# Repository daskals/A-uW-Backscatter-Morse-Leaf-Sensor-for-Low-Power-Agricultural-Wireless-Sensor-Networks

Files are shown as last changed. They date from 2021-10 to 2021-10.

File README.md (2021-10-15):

# A uW Backscatter-Morse-Leaf Sensor for Low-Power Agricultural Wireless Sensor Networks
Design files of IEEE publication: A uW Backscatter-Morse-Leaf Sensor for Low-Power Agricultural Wireless Sensor Networks

Nowadays, the monitoring of plant water stress
is of high importance in smart agriculture. Instead of the
traditional ground soil-moisture measurement, leaf sensing is a
new technology, which is used for the detection of plants needing
water. In this work, a novel, low-cost and low-power system for
leaf sensing using a new plant backscatter sensor node/tag is
presented. The latter, can result in the prevention of water waste
(water-use efficiency), when is connected to an irrigation system.
Specifically, the sensor measures the temperature differential
between the leaf and the air, which is directly related to the plant
water stress. Next, the tag collects the information from the leaf
sensor through an analog-to-digital converter (ADC), and then,
communicates remotely with a low-cost software-defined radio
(SDR) reader using monostatic backscatter architecture. The tag
consists of the sensor board, a microcontroller, an external timer
and an RF front-end for communication. The timer produces a
subcarrier frequency for simultaneous access of multiple tags.
The proposed work could be scaled and be a part of a large
backscatter wireless sensor network (WSN). The communication
protocol exploits the low-complexity Morse code modulation on
a 868 MHz carrier signal. The presented novel proof-of-consent
prototype is batteryless and was powered by a flexible solar panel
consuming power around 20 µW. The performance was validated
in an indoors environment where wireless communication was
successfully achieved up to 2 m distance.

**Authors:**

Spyridon Nektarios Daskalakis\
Stylianos D. Assimonis\
George Goussetis\
Manos M. Tentzeris\
Apostolos Georgiadis

---
IEEE Xplore: https://ieeexplore.ieee.org/document/8423620 \
Local: http://daskalakispiros.com/files/daskalalakis_sensors_2018.pdf

---

---
**Questions/issues**
Inquiries regarding the scripts provided are cordially welcome.

---
**Citing**

If you use our design, please cite [[1]](https://ieeexplore.ieee.org/document/8423620).

```bibtex
@article{daskalakis2018uw,
  title={A uW backscatter-morse-leaf sensor for low-power agricultural wireless sensor networks},
  author={Daskalakis, Spyridon Nektarios and Goussetis, George and Assimonis, Stylianos D and Tentzeris, Manos M and Georgiadis, Apostolos},
  journal={IEEE Sensors Journal},
  volume={18},
  number={19},
  pages={7889--7898},
  year={2018},
  publisher={IEEE}
}
 
```

[[1]](https://ieeexplore.ieee.org/document/8423620) S. N. Daskalakis, G. Goussetis, S. D. Assimonis, M. M. Tentzeris and A. Georgiadis, A uW Backscatter-Morse-Leaf Sensor for Low Power Agricultural Wireless Sensor Networks, IEEE Sensors Journal, Vol. 18, No. 19, pp. 7889–7898, Oct. 2018.

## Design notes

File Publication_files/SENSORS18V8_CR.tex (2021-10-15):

\documentclass[journal]{IEEEtran}

\usepackage{mathtools}
\usepackage{amsmath}
\usepackage{amssymb}
\usepackage{graphicx}
\usepackage{epstopdf}
\usepackage{cite}
\usepackage{array}
\usepackage{eurosym}
\usepackage{balance}
\usepackage{url}

\usepackage{color}

\newcommand{\hilight}[1]{\colorbox{yellow}{#1}}

\newcommand{\highlight}[1]{%
  \colorbox{yellow}{$\displaystyle#1$}}

\hyphenation{op-tical net-works semi-conduc-tor mo-nitoring}
\newcommand\blfootnote[1]{%
  \begingroup
  \renewcommand\thefootnote{}\footnote{#1}%
  \addtocounter{footnote}{-1}%
  \endgroup
}

\begin{document}
\title{A uW Backscatter-Morse-Leaf Sensor for Low-Power Agricultural Wireless Sensor Networks}

\author{

\IEEEauthorblockN{Spyridon N. Daskalakis,~\IEEEmembership{Student Member,~IEEE}, 
George Goussetis,~\IEEEmembership{Senior Member,~IEEE},
Stylianos D. Assimonis,
Manos M. Tentzeris,~\IEEEmembership{Fellow,~IEEE} and 
Apostolos Georgiadis,~\IEEEmembership{Senior Member,~IEEE}
}
                             
%\vspace{-1cm}
\thanks{
This work was supported by Lloyd's Register Foundation (LRF) and the International Consortium in Nanotechnology (ICON). The work of M. M. Tentzeris was supported by the National Science Foundation (NSF) and the Defense Threat Reduction Agency (DTRA).

An earlier version of this paper was presented at the  IEEE Sensors Conference, Glasgow, United Kingdom, 29 Oct - 01 Nov 2017  and was published in its Proceedings. Conference version of  this paper is available online at http://ieeexplore.ieee.org/document/8233888/.

S. N. Daskalakis, G. Goussetis and A. Georgiadis  are with School of Engineering \& Physical Sciences;  Institute of Sensors, Signals and Systems, Heriot-Watt University, Edinburgh, EH14 4AS, Scotland,
UK (e-mail: sd70@hw.ac.uk, g.goussetis@hw.ac.uk, apostolos.georgiadis@ieee.org).

S. D. Assimonis is with School of Electronics, Electrical Engineering \& Computer Science, Queen's University Belfast, Belfast, BT3  9DT, UK (e-mail: s.assimonis@qub.ac.uk).

M. M. Tentzeris is with School of Electrical and Computer Engineering, Georgia Institute of Technology, Atlanta, GA, 30332-250, USA (e-mail: etentze@ece.gatech.edu).

}}

\maketitle

\begin{abstract}
Nowadays, the monitoring of  plant water stress is of high importance in smart agriculture.
%
Instead of the traditional ground soil-moisture measurement, leaf sensing is a new technology, which is used for the detection of plants needing water.
%
In this work, a novel, low-cost and low-power system for leaf sensing using a new plant backscatter sensor node/tag is presented.
%
The latter, can result in the prevention of water waste (water-use efficiency), when is connected to an irrigation system.
%
Specifically, the sensor  measures the temperature differential between the leaf and the air, which is directly  related to the plant water stress.
%
Next, the tag collects the information from the leaf sensor through an analog-to-digital converter (ADC), and then, communicates remotely with 
a low-cost software-defined radio (SDR) reader  using monostatic backscatter architecture.
%
The tag  consists of  the sensor board, a microcontroller, an external timer  and an RF front-end for communication.
%
The timer produces a subcarrier frequency  
for simultaneous access of multiple tags.
%
The proposed work could be scaled and be a part of a large 
backscatter wireless sensor network (WSN). 
%
The communication protocol exploits 
the low-complexity  Morse code modulation
on a $868$~MHz carrier signal.
%
The presented novel  proof-of-consent prototype is batteryless and was powered by a flexible solar panel consuming power around $20~\mu$W.  
%
The performance was validated in an indoors environment where wireless communication was successfully achieved up to $2$~m distance.
%
\end{abstract}

\begin{IEEEkeywords}
Backscatter sensor networks, environmental monitoring, Internet-of-Things (IoT), leaf sensor, Morse code, precision agriculture, radio frequency identification (RFID) sensors, software-defined radio (SDR). 
\end{IEEEkeywords}

\IEEEpeerreviewmaketitle

\section{Introduction}
\label{sec:intro}
Precision agriculture allows farmers to maximize yields using minimal resources such as water, fertilizer, pesticides and seeds. 
%
By deploying sensors and monitoring fields, farmers can manage their crops at micro scale  \cite{ivanov2015precision}.
% 
This is also useful in order to predict diseases, conserve the resources and reduce the impacts of the environment. 
%
%Smart agriculture has roots going back to the 1980s when Global Positioning System (GPS) capability became accessible for civilian use. 
%
%Once farmers were able to accurately map their crop fields, they could monitor and apply fertilizer and weed treatments only to areas that required it. 
%
During the 1990s, early precision agriculture users adopted crop yield monitoring to generate fertilizer and pH correction recommendations. 
%
As more variables could be measured by sensors and were introduced into a crop model, more accurate recommendations could be made.
%
The combination of the aforementioned systems with wireless sensor networks (WSNs) allows multiple unassisted embedded devices (sensor nodes) to transmit  wirelessly data to central base stations \cite{ruiz2009review, yu2009zigbee}.
%
The base stations are able to store the data into cloud databases
for worldwide processing and visualization  \cite{fahmi2017prototype}. 
% 
Data (e.g., temperature, humidity, pressure) are collected from different on-board physical sensors: dielectric soil moisture sensors, for instance,  are widespread  for moisture measurements, since they can estimate the moisture levels through the dielectric constant of the soil, which changes as the soil moisture is changing.

%
Leaf sensing is an another way to measure the water status of a plant. 
%
When compared to soil moisture sensors, they can provide more accurate data since the measurements are directly taken on the plant and not through the soil or the atmosphere (air), which surround the latter \cite{palazzari2017leaf}. 
%
Commercial   leaf sensors  are involve   phytometric devices  that measure  the water deficit stress (WDS) by monitoring the moisture level in plant leaves. 
%
In recent work \cite{seelig2012irrigation}, a leaf sensor is used to measure the plant's leaf thickness in order to determine the WDS.
%
The  sensor is provided by  AgriHouse Inc.  and it is suitable for  real-time monitoring in  aeroponics, hydroponics and drip irrigation systems \cite{SG-1000}.
%
In an extreme WDS scenario, the leaf thickness decreased dramatically (by as much as $45$\%) within a short period of time ($2$~hours). 
%
On other occasions, the leaf thickness was kept fairly constant for several days, but decreased substantially when WDS became too severe for the plant \cite{seelig2012irrigation}.
%
Despite such favourable features, this class of sensors can only be used  in controlled environments (i.e., greenhouses) in  combination with other type of  sensors.
%
This is because a direct relationship seems to exist between leaf thickness and the relative humidity of the ambient air, temperature, soil temperature and soil salinity\cite{seelig2012irrigation}.  
%

A different type of leaf sensor for WDS monitoring,  is described in \cite{palazzari2017leaf} and is using two  temperature sensors.
%
The monitoring is based on  the temperature difference between the leaf and the air ($T_\text{leaf}- T_\text{air}$). 
% 
This difference is strictly related to the plant water stress and can be used as decision parameter in a  local irrigation system \cite{abraham2000irrigation}.
%
The first sensor measures the canopy temperature on  the leaf ($T_\text{leaf}$)  and the second the atmospheric temperature ($T_\text{air}$).
%
The use of canopy temperature as an indicator of crop water stress has been the subject of much research over the past $30$ years \cite{patel2001canopy}.
%
Canopy temperature and water stress are related: 
when the soil moisture is reduced,   stomatal closure occurs on the leaves resulting to reduced   transpirational cooling. 
%
The canopy temperature is then increased above that of the air
\cite{pearcy1971photosynthetic}.
%
In a plant with adequate water supply, the term  $T_\text{leaf}- T_\text{air}$ will be zero or negative, but
when the available water is limited, the difference will be
positive.

\begin{figure}[t]
\centering

\caption{Monostatic backscatter communication setup. Plant sensing is achieved by the tags and the information is sent back to a low-cost reader. Information is modulated using Morse coding on a $868$~MHz radiated carrier.}
\label{fig:backscatterlogic}
\end{figure}
The leaf sensors that were described above   are different from the well known leaf wetness  sensors (LWS).
%
The LWS can  detect the leaf wetness which is a meteorological parameter that describes the amount of dew and precipitation left on leaf surfaces. 
%
Leaf wetness can result from dew, fog, rain, and overhead irrigation.
%
Today, the LWS   are used most for  disease-warning systems 
\cite{hornero2017novel} and provided by companies like Davis Instruments Inc. and Meter Environment  Inc. \cite{PHYTOS-31}. 

The agricultural applications frequently involve large, expansive areas where wire connection for communication and power is undesirable or impracticable \cite{ruiz2009review}. 
%
The high-cost and the high-power requirements of the today WSN hardware prevent its usage in agriculture.
%
The deployment of these systems therefore relies  on reducing the cost to an affordable amount. 
%
Capital expenditure relates to the cost of the hardware, which should therefore be maintained minimum.
%
Energy autonomy for the sensor achieved by a combination of minimizing power consumption and harvesting ambient energy is likewise critical in order to reduce operational costs. 
%
Above factors drive the demand for low-cost, low-power WSN systems.

Backscatter radio communication (i.e., reflection and modulation of an incident radio frequency carrier) 
in combination with the use of energy assisted (or not) sensor tags is a method  that addresses aforementioned constraints.
%
It is used in radio frequency identification (RFID)
applications and offers ultra-low-power and low-cost aspects \cite{sample2008design}.  
%
The  wireless communication part of each tag can be 
simplified into a single radio frequency  (RF) transistor and an antenna, 
which can be used for each sensor tag to send information to a base station (reader).
%
It is a very energy-efficient communication technique
thus the RF signal is used not only for the communication, but also, for the power of the tag \cite{assimonis2015sensitive}.
%
In the recent literature,  backscatter WSNs  for smart agriculture purposes  \cite{daskalakis2016soil, kampianakis2014wireless, konstantopoulosconverting, pichorim2018two} were proposed. 
%
In \cite{daskalakis2016soil, kampianakis2014wireless},
soil moisture  and humidity  sensors were proposed.
%
A proof of concept demonstration was presented where the tags send measurements to a software-defined radio (SDR)
reader. 
%
The WSNs  employ semi-passive tags in bistatic topology and
each backscatter sensor tag has power consumption of the order of $1$~mW.
%
The achieved communication range  (tag-reader distance) is of the order of $100$~m; this is achieved by supplying the tags with small batteries thereby enabling increased communication range.
%
In \cite{konstantopoulosconverting},  electric potential (EP) signals of plants can be measured by the tag in order to estimate when the plant needs water; in this work, the tags are batteryless and they harvest energy from the plant itself.
%
In \cite{pichorim2018two}  two UHF RFID sensor nodes  for soil moisture sensing were designed based on conventional RFID chips.

This work discusses the implementation of a low-cost and low-power wireless sensor system for agricultural applications, which uses a novel plant, backscatter sensor node/tag.
%
Preliminary results on this sensor node were proposed in \cite{daskalakis2017backscatter}.
%
The tag is connected with a temperature leaf sensor board  for WDS measurements and reflects RF signals from a carrier emitter.
%
It is noted that the proposed system can be a part of a backscatter WSN, transmitting   data to a reader as shown in Fig.~\ref{fig:backscatterlogic}.
%
Specifically the tag architecture  consists of a microcontroller (MCU) and an external timer for the modulation.
%
There is also a sensor board for the   measurements and
an FR front-end for the backscatter communication.
%
The tag reads the information from the sensors and generates pulses that control an RF switch. 
%

The low complexity Morse code technique was selected for the backscatter modulation and it is the first time that  Morse code is used in a backscatter WSN system. 
%
Morse code uses On-Off-Keying (OOK) modulation  which means that a  frequency  signal exists in only two states either ``On" or  ``Off".
%
Morse code and OOK contribute to architectural and power consumption efficiencies for the tag.
%
A low-cost   SDR is used as  reader and collects the signals for further processing. 
%
The $868$~MHz in the European RFID band was selected as carrier emitter frequency.

The structure of the this paper  is as follows: Section~\ref{sec:Backscatter_morse} provides the basic principles of backscatter  communication and the Morse encoding.
%
In  Section~\ref{sec:tag} the design  and the implementation of the tag is described. 
%
Section~\ref{sec:receiver} discusses the hardware and software part of the low-cost
receiver. 
%
Section~\ref{sec:exp} presents the  proof-of-concept experimental setup and a communication indoor demo.
%
In Section~\ref{sec:comparison}, the benefits of our proposed low-power WSN and future work are discussed.
%
Finally, section~\ref{sec:conclusion} includes concluding remarks.

\section{Backscatter and Morse Encoding}
\label{sec:Backscatter_morse}

\begin{figure}[t]
\centering

\caption{Left: In Backscatter principle when a $F_c$ carrier  exists 
and the RF switch frequency is $F_\text{tag}$, two subcarriers appear with frequencies $F\text{c} \pm F_\text{tag}$.
Right: Morse code symbols.}
\label{fig:morse}
\end{figure}

A typical  backscatter communication system requires three devices: a tag, an emitter and a reader. 
%
Traditional batteryless RFID systems utilize monostatic architectures, where the reader and the emitter are  in the same box.
%
In this work this architecture is employed; the emitter transmits a continuous wave (CW) signal at frequency $F_\text{c}$ = $868$~MHz.
%
The tag receives  and scatters a fraction of it back to the reader as shown in Fig.~\ref{fig:backscatterlogic}.
%
The backscatter binary communication can be implemented on the tag using an RF switch, an antenna and a control unit.
%
The switch  alternates the load of the antenna between two values ($Z_{1/2}$) and offers two reflection coefficients, ($\Gamma_{1/2}$), according to
%	
\begin{align}
\Gamma_\text{1/2}=\frac{Z_\text{1/2}-Z^{*}_\text{a}}{Z_\text{1/2}+Z_\text{a}},
\label{eq:gamma}
\end{align}
%
with  $Z_\text{a}$,  the antenna impedance  equal with $50$~Ohm. 
%
When the CW  with frequency $F_\text{c}$ arrives on the antenna
and the  RF switch frequency is $F_\text{tag}$, frequency modulation occurs and two subcarriers appear in the spectrum with frequencies $F_{\text{sub1/2}} = F_{\text{c}} \pm F_{\text{tag}}$.
%
The reflected signal (subcarriers) and the carrier  are depicted in Fig.~\ref{fig:morse} (left). 
%
The subcarriers are  next modulated  using the Morse code scheme as it is described below.

Morse code is a method of transmitting text information as a series of On-Off tones, named after the inventor of the telegraph Samuel F. B. Morse  in the 1830s \cite{fahie1884history}.
%
It is referred as the earliest type of binary digital communications
since the code is made solely from ones and zeros (``On" and ``Off"). 
%
%In modern times Morse code is still used widely in amateur radio communications, as Morse  coded signals can get a message through noise, whereas a voice signal often cannot.
%
Each letter of the alphabet is translated to combinations of dots  ``."  and dashes  ``-" that are sent over telegraph wires or by radio waves from one place to another.
%
For example, the  letter ``A" is translated to the sequence ``.-" with elements one dot and one dash symbol.
%
Lets assume that  the duration of a dot ($T_\text{dot}$) is one unit, then  the duration a dash is three units ($3T_\text{dot}$). 
%
Dot and dash symbols are followed by a short silence, equal to one unit (Fig.~\ref{fig:morse}, right). 
%
The space between the elements of one letter/character is one unit, between characters is three units and between words, seven units.

\begin{figure}[t]
\centering

\caption{Printed circuit boards of the tag and the solar cell.
The  watchdog timer (top) and the timer  module (bottom)  are connected with the main processor unit in the middle.}
\label{fig:PCBs}
\end{figure}
The Morse code is the only digital modulation  designed to be easily read without a computer.
%
Today it is usually used by radio amateurs and it is the  fist time that is used in backscatter communication.
%
The OOK modulation is  used to transmit Morse code signals  over  a  fixed radio frequency.
%
The OOK  is a simplest form of amplitude-shift keying (ASK) modulation that can represent digital data using  a presence (``On") or an absence (``Off") of a carrier signal.
%
With  OOK modulation and thus Morse code,  the complexity of the receiver and the tag is drastically simplified compared to a frequency modulation (FM) scheme thus there is no need for a different frequency for each symbol \cite{proakis2008digital}.
%
Also, Morse code was designed so that the most frequently used letters have the shortest codes. In general, code length increases as frequency decreases. 

In this work the ``."  (dot of Morse code) is implemented as a  signal with a specific duration $T_\text{dot}$ and frequency $F_\text{tag}$.
%
As it is expected the ``-"  (dash in Morse code) is then implemented using a signal of the same frequency with duration equal to three times that of the dot signal.
%
The $T_\text{dot}$ is defined by the MCU and the  $F_\text{tag}$ is defined by the external timer of the tag.
%
The dot and dash frequency signals are shown in Fig.~\ref{fig:morse} (left). 
%
The speed of Morse code is stated in words per minute (WPM) and 
according to the standards, the word PARIS is used to determine it. 
%
The word is translated to exactly $50$ units and  one dot duration is defined by the formula:
$T_\text{dot} = 1200 / \text{WPM}$ with $T_\text{dot}$ in ms. 

\section{Tag Implementation}
\label{sec:tag}

\subsection{Main Unit}
\label{subsec:mainunit}

\begin{figure}[t]
\centering

\caption{The schematic of the tag's main unit. The main part, is a low-power MCU that controls the sensors, the timer and the RF front-end.}
\label{fig:main_unit}
\end{figure}

The proof-of-concept tag consists of five different parts  implemented in  different printed circuit boards (PCBs) for simplifying debugging. 
%
These parts are the MCU unit, the timer part, the watchdog timer part, the sensor board, and finally the RF front-end. 
%
The MCU unit (Fig.~\ref{fig:PCBs}, middle) is the main part of the system and it is responsible for the data sensor acquisition, the implementation of the Morse code symbols and the control of the other parts. 
%
The schematic of the main system is depicted in Fig.~\ref{fig:main_unit}.
%
The ultra-low-power $8$-bit PIC16LF1459  from Microchip with current consumption  of only $25~\mu$A/MHz at $1.8$~V \cite{PIC16LF1459} was selected for the MCU.
%
The MCU collects data from the sensor board using the embedded analog-to-digital converter (ADC) with $10$-bit resolution.
%
It contains also a digital-to-analog converter (DAC) with $5$-bit resolution.     
%
The internal $31$~kHz low-power  oscillator was utilized as clock source in order to reduce the  power consumption of the tag.
The  MCU is responsible to supply  all the other parts with  voltage when  it is necessary.
%
The main part is connected with a $\mu$W timer for the subcarrier signal ($F_\text{tag}$) production 
and an external watchdog timer to wake up the MCU from the ``sleep" operation mode. 
%
In sleep mode the MCU  current consumption was only $0.6~\mu$A at  $1.8$~V.
%

\subsection{Timers}
\label{subsec:Timers}

\begin{figure}[t]
\centering

\caption{Timer and  RF front-end schematic of the tag. The timer produces  square wave pulses with $50\%$ duty circle and supplies the RF front-end through a modulation switch (ADG902). The ADG902 switch is controlled by the MCU.}
\label{fig:timer}
\end{figure}

The timer module (Fig.~\ref{fig:PCBs}, bottom) consists of a very low-power timer (TS3002), a voltage reference and a switch.
%
It is responsible for producing the subcarrier frequency of the tag  $F_\text{tag}$ and modulating this subcarrier through the  switch. 
%
The low-power,  single-pole single-throw   (SPST) switch ADG902  was used in this case and  one of the MCU input/output (I/O) pins was programmed to provide the necessary  Morse code  pulses  for the control.
%
The implemented circuit is depicted in Fig.~\ref{fig:timer}.
%
The TS3002 is a  CMOS oscillator provided by Silicon Labs Inc., fully 
specified to operate at around $1$~V  and to consume current lower than  $5~\mu$A  with an output frequency range from $5.2$~kHz to $290$~kHz  \cite{TS3002}.
%
The timer  was supplied by  a voltage reference integrated circuit (IC) XC6504 at $1.2$~V   \cite{XC6504}  in order to reduce the power consumption. 
%
XC6504 provides also stable reference voltage at the ADC  of the tag  and it is activated by an I/O pin of MCU.
%
The output frequency of the timer is programmed by using two parallel external resistors, a capacitor and a voltage value. 
%
The square wave pulses  have  $50~\%$ duty
cycle and the   maximum oscillation frequency when a zero voltage is applied at $V_\text{prog}$, is given by
%
\begin{align}
F_\text{tag,max} &=  \frac{1}{1.19  C_{1} R_\text{set}},
\label{eq:fmax}
\end{align}
with  $R_\text{set}= R_\text{1}R_\text{2}/(R_\text{1}+R_\text{2})$.
%
In our proof-of-concept prototype  two  identical resistors were used with value of $6.2$~MOhm and tolerance $1\%$ in order to avoid the frequency jitter.
%
The output frequency was programmed to $34.3$~kHz and the power consumption of the timer circuit was measured at $2.62$~uW.
%
The  above measurement includes the power consumption of the  voltage reference IC.
%
%The timer module was fabricated in a separate PCB for debug purposes  and is depicted in Fig.~\ref{fig:PCBs} (Bottom). 
%
%
The TS3002 can be configured as a voltage controlled oscillator (VCO) by applying  a positive voltage value at  $V_\text{prog}$ terminal and the $F_{\text{tag}}$ frequency  is defined as \cite{KonstantopoulosMSc}:
%
\begin{align}
F_\text{tag}&=V_\text{prog} \frac{-F_\text{tag,max} }{V_\text{prog,max}}+F_\text{tag,max},
\label{eq:fmax}
\end{align}
%
with $V_\text{prog,max}$,   the maximum value of  $V_\text{prog}$ when the timer gives zero frequency at its output. 
%
In Fig.~\ref{fig:timer_power} the ultra-low-power consumption of the timer versus different frequencies at the output is shown. 
%
Each frequency value corresponds to a different control voltage value ($V_\text{prog}$).   
%
\begin{figure}[t]
\centering

\caption{Power consumption of the TS3002 timer versus the output frequency ($F_\text{tag}$) versus the control voltage $V_\text{prog}$.}
\label{fig:timer_power}
\end{figure}

In case of a multiple access scheme, we have multiple tags in the same network sending information simultaneously. 
%
Each tag must operate in  different $F_{\text{tag}}$  frequency  and the embedded  DAC could be used in order to tune every tag in different subcarrier. 
%
The DAC can supply the timer with $2^5$ distinct voltage levels ($V_\text{prog}$) corresponding to $32$ distinct subcarriers resulting in $32$ tags in the same network.
%
In this work the DAC is not used in order to reduce the overall power consumption of the prototype tag. 
%
The  subcarrier frequency was programmed manually by using the two resistors and $V_\text{prog}$ terminal was connected to the ground.

For minimization of the average power consumption, a duty cycle operation of the tag was programmed.
%
The tag was active only for a desired minimum period of time and a watchdog timer was  used  as a real-time clock (RTC). 
%
Specifically, the nano power TPL5010 timer from Texas Instruments \cite{instrumentsTPL5010} 
 was utilized, which consumes  only $35$~nA.
%
The timer can work as RTC and allows the MCU to be placed in  sleep mode.  
%
The timer can provide an interrupt signal in selectable timing intervals from $0.1$ to $7200$~s by programming  two external parallel resistors.
%
It was programmed to wake up the MCU every $4$~s 
activating the duty cycle operation of the system.
%
The PCB of the watchdog timer is shown in Fig.~\ref{fig:PCBs} (top).

\subsection{Sensor Board}
\label{subsec:sensorboard}

\begin{figure}[t]
\centering

\caption{Printed circuit board with  low-power LMT84 temperature sensors. The  sensor board can be placed easily on a leaf.}
\label{fig:sensboard}
\end{figure}

The sensor board consists of two  analog  temperature sensors ``LMT84" by Texas Instruments (Fig.~\ref{fig:sensboard}, left).
Each sensor is connected with an  ADC input  and consumes $5.4~\mu$A  at $1.8$~V  \cite{instrumentsLMT84}.
%
The accuracy of each one is $\pm 0.4^\circ C$, while both were placed on a ``clip" scheme board in order to be easily mounted on a leaf. 
%
The prototype placed on a leaf is depicted in  Fig.~\ref{fig:sensboard}, (right).
%
The temperature sensor seen on the top measures the air temperature ($T_\text{air}$), while a similar sensor under the leaf surface is placed in direct contact with the leaf and  measures the canopy temperature $T_\text{leaf}$. 
The transfer function of the each sensor is defined as \cite{instrumentsLMT84}:
\begin{align}
T_\text{leaf/air} &= \frac{5.506-\sqrt{36.445-0.00704V_\text{leaf/air}}} {-0.00352
}+30,
\label{eq:temp}
\end{align}
%
where $V_\text{leaf/air}$ is the ADC value in mV and $T_\text{leaf/air}$ is temperature in $^\circ C$. The MCU collects  data from sensors one by one in order to minimize the instantaneous power consumption. 
%
The two  ADC  measurements were encoded using the Morse code and were sent back to the receiver. 
%
At the receiver, the signal from both sensors is decoded in terms of a voltage value (in mV) and the temperature is then calculated using formula (\ref{eq:temp}). Subsequently, the temperature difference  $T_\text{leaf}-T_\text{air}$ is estimated and recorded.

\subsection{RF Front-end}
\label{subsec:watchdog}

\begin{figure}[t]
\centering

\caption{Top: Low-cost software-defined radio. Bottom: RF front-end board with ADG919 switch.}
\label{fig:rffront}
\end{figure}

The RF front-end part consists of an RF switch and a custom dipole antenna as it is depicted in Fig.~\ref{fig:rffront} (bottom).  
%
The RF front-end  is connected to the ADG902 switch of the timer module (Fig.~\ref{fig:timer}). 
%
It is used  for the wireless communication with the reader  and  it it responsible for creating the reflections of the incident CW signal.
%
The single-pole, double-throw  (SPDT) switch ADG919 \cite{ADG919} was selected due to its
low insertion loss  and high ``OFF" isolation. 
% 
The ``RFC"  and the  ``RF2" terminals of the RF switch were connected to the two arms of dipole antenna.
%
It was connected directly with the RF switch without  an SMA connector in order to avoid the connectors losses.  
%
The dipole antenna  has omnidirectional attributes at the vertical to its axis level and was designed for operation at $868$~MHz. 
%
The bottom picture of Fig.~\ref{fig:rffront} shows the fabricated prototype  and the dimensions of the antenna. 
%
The RF Front-end  was fabricated  using copper tape on cardboard substrate.

\subsection{Tag Analysis}
\label{subsec:taganalysis}

In this work  a solar panel harvester was employed  for powering the tag.
%
Solar  energy could be used to power the tag also in combination with other energy harvesting technologies \cite{niotaki2014solar}. 
%
This solar module is the flexible, thin-film SP3-37  provided by  PowerFilm Inc. \cite{SP3-37}.
%
The solar panel charges a $11$~mF super capacitor (CPH3225A) instead of a battery through a low voltage drop  Schottky diode. 
%
For the diode, the SMS7630-079LF by Skyworks Inc. with forward voltage drop only $150$~mV was selected. 
%
The solar panel, the diode and the capacitor positions are depicted in Fig.~\ref{fig:PCBs}. 

\begin{figure}[t]
\centering

\caption{Flow chart of the tag algorithm. This algorithm was implemented in the MCU and controls all the peripherals of the tag.}
\label{fig:tagalgorithm}
\end{figure}

On the tag, a real-time algorithm  was implemented in order to read
the sensor information and  wirelessly transmit it to the receiver. 
%
The steps of the algorithm are  shown in Fig.~\ref{fig:tagalgorithm}.
%
Initially, an interrupt signal coming from  the watchdog timer is used to wake up the MCU. 
%
Next, initialization of the system (ADC, clock, I/O pins) is achieved and the ADC is enabled for data capture.  
%
The two temperature sensors are  consecutively powered  and the ADC
reads the data from each one.
%
The ADC is turned off immediately after this action for reducing the energy consumption.
%
In the next step, the  TS3002 timer and the  ADG902/919 switches are switched on two steps before the data sending.
%
 This is necessary for the frequency stabilization of the timer.
%
The tag was programmed to send a Morse coded word with fixed format
every time  the algorithm is running.
% 
The format of the word was defined as  ``$ADC_\text{DATA1}$\textbf{E}$ADC_\text{DATA2}$"
with $ADC_\text{DATA1}$, $ADC_\text{DATA2}$,  the ADC values, varied for $0$ to $1023$. 
%
The sensor data were separated by the letter ``E" and there are not any spaces between them. 
%
The goal was to create a short word to minimize the  transmission time and thus the energy consumption.
% 
The letter ``E" is the most common letter in English alphabet and has the shortest code, a single dot.
%
The word is then translated in dots and dashes using the frequency  $F_\text{tag}$ of the timer and  baseband pulses coming from the MCU. 
%
\begin{figure}[t]
\centering

\caption{Oscilloscope measurement of a Morse coded word: ``. . - - - ~ . ~ . . . . -" corresponding to ''$2$\textbf{E}$4$" word. This  square wave signal is used to control the RF front-end.}
\label{fig:word}
\end{figure}
%

The MCU produces  baseband pulses that contain the dots, dashes  and  the spaces between them.
%
This signal is  coming  from  an  I/O  pin and is used to modulate the timer's frequency signal through the ADG902  switch.
%
In Fig.~\ref{fig:word} an oscilloscope  measurement of a modulated  example signal 
at  the  output of ADG902 switch  is shown.
%
%
The depicted word is the ``$2$\textbf{E}$4$" which is translated in ``. . - - - ~ . ~ . . . . -", while 
%
each dot/dash is a $33$~kHz signal with different duration.
%
The required spaces between the  Morse code symbols can also be observed.
%
%
In order to send this word wirelessly, the RF switch ADG919 is fed with this signal and the incident CW carrier is modulated again by the tag information. 
%
In the last step of the algorithm, the  switches and the timer  were switched off and the tag  goes to sleep mode.
%
The time duration of the algorithm depends from the ADC data and the  worst-case scenario is the word  ``$1023$\textbf{E}$1023$". 
%
In that case  the duration of the hole process lasts $2.8$~s assuming $104.3$~WPM speed.

\section{Receiver}
\label{sec:receiver}

\begin{figure}[t]
\centering

\caption{Flow chart of the real-time receiver algorithm. The decoding algorithm was implemented in MATLAB software.}
\label{fig:recalg}
\end{figure} 

In our system the  temperature  ADC data are received  by a low-cost SDR. 
%
This receiver is the   ``NESDR SMArt" SDR available by the NooElec   Inc. (Fig.~\ref{fig:rffront}, top) \cite{NESDR}.
%
It is an improved version of classic RTL SDR dongle based on the same
RTL2832U demodulator with USB interface and R820T2 tuner. 
%
The tuning frequency range varies  from $24$~MHz to $1850$~MHz with sampling rate up to
$2.8$~MS/s and noise figure about $3.5$~dB. 
%
Gain control is also provided through the embedded low noise amplifier (LNA)
at the input of R820T2, while  at the output through a variable gain amplifier (VGA). 
%
It  down-converts the received RF signal to baseband and it  sends real (I) and imaginary (Q) signal samples to a computer through an USB interface. 
%
All the above parameters  make it suitable for our application also noting that the required sampling rate is quite low ($250$~kS/s) and it costs only    $12.8$~GBP. 
%
The receiver  was connected with a $868$~MHz monopole antenna to receive the signals from the tag.
%
\begin{figure}[t]
\centering

\caption{A received signal including a Morse coded word in three different steps of decoding algorithm.}
\label{fig:recword}
\end{figure}

A real-time algorithm was implemented in MATLAB in order to detect the reflected signals.
%
The SDR can be connected with MATLAB through the open course GNU radio framework  \cite{radio2007gnu}. 
%
In the algorithm, the subcarrier frequency  $F_\text{tag}$   of the tag is known and the algorithm  collects   data in a window with duration: $2 \times$length(maximum word).
%
As shown in Fig.~\ref{fig:recalg}, the received I and Q digitized 
samples  were combined together in  complex numbers.
%
Carrier frequency offset  (CFO) was estimated and 
the signal was corrected.
%
This accounts for the difference in carrier frequency between the SDR and the emitter, providing the  variance between the real values and the estimated values of the subcarrier signal.
%
The  CFO was estimated after the samples were collected and then all samples were frequency shifted accordingly.
%
The absolute value  is taken and  a bandpass  filter with center frequency $F_\text{tag}$ is  applied  in order to appear the Morse code word.
%
After considering the signal magnitude, a matched filter was  applied to appear the baseband Mode symbols.
%
The matched filter is  a square pulse with duration $T_\text{dot}$.
%
The received  signal  of the Fig.~\ref{fig:word}  word is shown  in Fig.~\ref{fig:recword}, (a) after the Band-pass filtering.
%
In  Fig.~\ref{fig:recword}, (b) is shown the  above signal  after matched filtering.
%
The matched filtering was followed by downsampling with a factor of $100$
for reducing of the computational complexity.
%
Next, the received signal must be digitized using a threshold level.
%
AGC  (automatic gain control) and threshold decision is needed because the signal strength varies  over time. 
%
The digitization  procedure, which is using a  suitable threshold, is depicted in Fig.~\ref{fig:recword}, (c).
%
The digitized signal was classified in order to detect the Morse code symbols and thus the alphabet characters.
% 
For the classification, a group of tokens was used with each token to be an
English alphabet character translated in dots and dashes.
%
The output of the algorithm is the English text and number representation of the Morse word.

\section{Experimental results}
\label{sec:exp}
%
\begin{figure}[t]
\centering

\caption{Experimental indoor backscatter topology. The tag was measured in monostatic architecture $2$~m away from  emitter and  receiver antennas.}
\label{fig:indoor}
\end{figure}
%
The proof-of-concept system was tested indoors 
in a setup depicted in  Fig.~\ref{fig:indoor} in order to validate the effectiveness of our  backscatter communication system.
%
The emitter, the tag and the reader were tested in  monostatic  architecture  in Heriot-Watt University electromagnetics lab.
%
A signal generator with a monopole antenna  was utilized as the CW emitter at $868$~MHz, with a transmission power of
$13$~dBm.
%
The SDR reader  was used as the software-defined
receiver in the same  position with the emitter.
%
The receiver was tuned to $868$~MHz  with sampling rate $250$~kbps. 
%
The distance between the reader and  emitter antenna was fixed at $17.27$~cm ($\lambda/2$).
%
The tag was placed $2$~m away from the emitter/reader antennas and was programmed to produce  words with Morse code symbols. 
%
Each word contains   the  $T_\text{leaf}$ and $T_\text{air}$ values in mV at $104.3$~WPM speed.
%
The sensor node has low-power consumption and was supplied by the solar panel  and the super capacitor.
%
An office lamb was used  as an  indoor source of light.
%
Results shown that the transmitted words can be presented clearly at the receiver.  

Table \ref{tab:BOM} provides cost of the most significant components of the tag  and the current consumption of each one.
%
In active mode,  the maximum  overall dissipated  current  at $1.8$~V was measured $11.5~\mu$A ($20.7~\mu$W) when the ADC was  off and $201~\mu$A  ($362~\mu$W) when the ADC was active.
%
In the sleep mode operation the current consumption was $0.6~\mu$A ($1~\mu$W). 
%
Finally, using discrete  electronic components in terms of bill of materials (BOM), the tag results in the cost  of $14.1$~GBP
 and
the prices of each component were found from online suppliers on the order of one. 
% 

Looking at the market, we found only one leaf sensor provided by Agrihouse Inc.  
%
It costs $290$~USD without the wireless communication equipment  and according to the above, this work seems to be a promising  low-cost alternative solution in order to monitor the WDS of the plans.
%
%

\begin{table}[t]	
\renewcommand{\arraystretch}{1.4}
\centering
\caption{Tag Current Consumption \& Cost Analysis}
\scalebox{0.9}
{
\begin{tabular}{c||c||c}
\hline
\hline
%\begin{tabular}[x]{@{}c@{}}MSE(Hz$^2$)\\pre-filt.\end{tabular} For forcing newline in cell
 Tag Part & Cost (GBP)  & Current ($\mu A$)\\
\hline
\hline
MCU (PIC16F1459)&$1.44$ & -\\
 ACTIVE MODE (ADC OFF) & -& 3.3 $@ V_\text{DD}=1.8$~V\\
 ACTIVE MODE (ADC ON) &- & 198.4 $@ V_\text{DD}=1.8$~V\\
 SLEEP MODE &- & 0.6 $@ V_\text{DD}=1.8$~V\\
\hline
Timer (TS3002)&$0.54$ & $2.2$ $@ V_\text{DD}=1.2$~V\\
\hline
Voltage Reference (XC6504)& $0.42$ & $0.6$ $@ V_\text{DD}=1.8$~V\\
\hline
Watchdog timer (TPL5010) & $0.93$ & $0.035$ $@ V_\text{DD}=1.8$~V \\
\hline
RF Switches (ADG902+ADG919) & $2.39+2.49$ &  $0.1$ $@ V_\text{DD}=1.8$~V\\
\hline
Temp Sensors ($2 \times$LMT84)&$0.64+0.64$& $5.3$ $@ V_\text{DD}=1.8$~V \\
\hline
Super Cap (CPH3225A)&$2.05$& - \\
\hline
Solar Panel (SP3-37)&$2.20$& - \\
\hline
\hline
Sum&$14.16$& -\\
Sum ACTIVE MODE (ADC OFF) &-& 11.5 $@ V_\text{DD}=1.8$~V\\
Sum ACTIVE MODE (ADC ON) &-&  201  $@ V_\text{DD}=1.8$~V\\
Sum SLEEP MODE &- & 0.6 $@ V_\text{DD}=1.8$~V\\
\hline
\hline
\end{tabular}
}
\label{tab:BOM}
\end{table}
%
\section{System considerations \& Future Work}
\label{sec:comparison}
%
%
The architecture of the proposed WSN  could include many  low-cost emitters/readers, installed in a
field and around them, multiple, backscatter sensors can be  spread.
%
Working in cells that contain groups of tags, each tag can backscatter information to the receiver at a   specific subcarrier frequency.
%
The tags inside each cell will employ  frequency-division-multiple-access (FDMA) scheme, whereas the  emitters/readers  could operate in a time-division-multiple-access (TDMA) scheme. 
%
Using the above concept the development of a backscatter  sensor network,  could include hundreds of low-cost tags.

%
The classic  WSN nodes utilize duty cycling operation in
order to decrease the power consumption thus extending WSN lifetime.
%
In this work, the  tag was designed such that as low as possible power and the utilization of duty cycling could further decrease the required energy requirements.
%
In \cite{kampianakis2014wireless} was demonstrated that the power consumption of a similar proposed backscatter WSN is lower than a ZigBee-type WSN. 
%
ZigBee sensors are based on IEEE 802.15.4 communication protocol and are widespread for  wireless area networks with small digital radios \cite{baronti2007wireless}.

Future work will focus on sensing and communication measurements and  
on  further deceasing the overall cost of the sensor node.
%
A future challenge is  also to  design an RF  electromagnetic energy  harvester  to combine all the different forms of ambient energy availability.
%
The communication range of  the above deployment can be extended  by the
following modifications.
%
First, it is possible to use circular polarized and directive antennas instead on the monopoles at the  receiver and the reader. 
%
%
The antennas  would be  designed and fabricated on the same substrate with    
a proper distance  between them in order to maximize gain  and keep mutual coupling between them at low level. 
%
With circular polarization the alignment between the reader/emitter antenna and the tag will have less effect.
%
Secondly, the RF front-end dipole antenna could be replaced with a better gain antenna. 
%
This work is a first attempt to design  a low-cost and low-power leaf sensor  for agriculture  and specific sensing plant measurements  will be prepared in the future. 
%
The proposed sensor must be calibrated for different values on relative humidity and soil moisture for a  specific type of plant. 
%
Finally, the cost of the tag can be reduced by replacement  of  the super capacitor  and the solar panel with  a cheaper option.
%
%
%
\section{Conclusion}
\label{sec:conclusion}
%
In this paper a novel  backscatter leaf sensing system for agricultural purposes was presented. 
%
Specifically, it includes a  sensor for leaf canopy temperature measurements and  it  can be used for  water stress measurements on plants.
%
The sensor node has low-power consumption of only $20~\mu$W and is supplied by a solar panel without need of battery.
%
Morse code modulation was used for the wireless communication
with a low-cost SDR receiver by backscattering RF signals from a carrier emitter.
%
The proposed system  is part of the  backscatter WSN for agriculture  with a small cost per sensor node.
%
It is suitable for distributed monitoring of environmental parameters in largescale, precision agriculture applications.
%

\section*{Acknowledgment}
\normalsize 
The authors would like to thank  Alexios Costouri and all members of  Microwave Lab, Heriot-Watt University, Edinburgh, UK  for their help in various steps throughout this work. 

% Generated by IEEEtran.bst, version: 1.14 (2015/08/26)
\begin{thebibliography}{10}
\providecommand{\url}[1]{#1}
\csname url@samestyle\endcsname
\providecommand{\newblock}{\relax}
\providecommand{\bibinfo}[2]{#2}
\providecommand{\BIBentrySTDinterwordspacing}{\spaceskip=0pt\relax}
\providecommand{\BIBentryALTinterwordstretchfactor}{4}
\providecommand{\BIBentryALTinterwordspacing}{\spaceskip=\fontdimen2\font plus
\BIBentryALTinterwordstretchfactor\fontdimen3\font minus
  \fontdimen4\font\relax}
\providecommand{\BIBforeignlanguage}[2]{{%
\expandafter\ifx\csname l@#1\endcsname\relax
\typeout{** WARNING: IEEEtran.bst: No hyphenation pattern has been}%
\typeout{** loaded for the language `#1'. Using the pattern for}%
\typeout{** the default language instead.}%
\else
\language=\csname l@#1\endcsname
\fi
#2}}
\providecommand{\BIBdecl}{\relax}
\BIBdecl

\bibitem{ivanov2015precision}
S.~Ivanov, K.~Bhargava, and W.~Donnelly, ``Precision farming: Sensor
  analytics,'' \emph{{IEEE} Intelligent Systems J.}, vol.~30, no.~4, pp.
  76--80, Jul. 2015.

\bibitem{ruiz2009review}
L.~Ruiz-Garcia, L.~Lunadei, P.~Barreiro, and I.~Robla, ``A review of wireless
  sensor technologies and applications in agriculture and food industry: state
  of the art and current trends,'' \emph{Molecular Diversity Preservation
  International Open Access Sensors J.}, vol.~9, no.~6, pp. 4728--4750, Jun.
  2009.

\bibitem{yu2009zigbee}
C.~Yu, Y.~Cui, L.~Zhang, and S.~Yang, ``Zigbee wireless sensor network in
  environmental monitoring applications,'' in \emph{Proc. {IEEE} Conf. on
  Wireless Commun. Networking and Mob. Comput. (WiCOM)}, Binjiang, {C}hina,
  Sept. 2009, pp. 1--5.

\bibitem{fahmi2017prototype}
N.~Fahmi, S.~Huda, E.~Prayitno, M.~U.~H. Al~Rasyid, M.~C. Roziqin, and M.~U.
  Pamenang, ``A prototype of monitoring precision agriculture system based on
  {WSN},'' in \emph{Proc. {IEEE} Int. Sem. on Intelligent Technology and Its
  Applications (ISITIA)}, {S}urabaya, {I}ndonesia, Aug. 2017, pp. 323--328.

\bibitem{palazzari2017leaf}
V.~Palazzari, P.~Mezzanotte, F.~Alimenti, F.~Fratini, G.~Orecchini, and
  L.~Roselli, ``Leaf compatible “eco-friendly” temperature sensor clip for
  high density monitoring wireless networks,'' \emph{{Cambridge Univ. Press}
  Wireless Power Transfer}, vol.~4, no.~1, pp. 55--60, Feb. 2017.

\bibitem{seelig2012irrigation}
H.-D. Seelig, R.~J. Stoner, and J.~C. Linden, ``Irrigation control of cowpea
  plants using the measurement of leaf thickness under greenhouse conditions,''
  \emph{Springer J. Irrigation Science}, vol.~30, no.~4, pp. 247--257, Jul.
  2012.

\bibitem{SG-1000}
\BIBentryALTinterwordspacing
\emph{SG-1000 Leaf Sensor}, AgriHouse Inc., 2017. [Online]. Available:
  \url{https://www.biocontrols.com/Leaf%20Sensor/SG-1000softwareV1.pdf}
\BIBentrySTDinterwordspacing

\bibitem{abraham2000irrigation}
N.~Abraham, P.~Hema, E.~Saritha, and S.~Subramannian, ``Irrigation automation
  based on soil electrical conductivity and leaf temperature,'' \emph{Elsevier
  Agricultural Water Management J.}, vol.~45, no.~2, pp. 145--157, Jul. 2000.

\bibitem{patel2001canopy}
N.~Patel, A.~Mehta, and A.~Shekh, ``Canopy temperature and water stress
  quantificaiton in rainfed pigeonpea ({C}ajanus cajan ({L}.) {M}illsp.),''
  \emph{Elsevier, Agricultural and Forest Meteorology}, vol. 109, no.~3, pp.
  223--232, Sep. 2001.

\bibitem{pearcy1971photosynthetic}
R.~Pearcy, O.~Bjorkman, A.~Harrison, and H.~Mooney, ``Photosynthetic
  performance of two desert species with {C4} photosynthesis in {D}eath
  {V}alley, {C}alifornia,'' \emph{Carnegie Institute Year Book}, vol.~70, pp.
  540--550, 1971.

\bibitem{hornero2017novel}
G.~Hornero, J.~E. Gait{\'a}n-Pitre, E.~Serrano-Finetti, O.~Casas, and
  R.~Pallas-Areny, ``A novel low-cost smart leaf wetness sensor,''
  \emph{Elsevier, Computers and Electronics in Agriculture}, vol. 143, pp.
  286--292, Dec. 2017.

\bibitem{PHYTOS-31}
\BIBentryALTinterwordspacing
\emph{PHYTOS 31, Dielectric Leaf Wetness Sensor, product manual}, Decagon
  Devices, Inc., 2016. [Online]. Available:
  \url{http://library.metergroup.com/Manuals/10386_Leaf%20Wetness%20Sensor_Web.pdf}
\BIBentrySTDinterwordspacing

\bibitem{sample2008design}
A.~P. Sample, D.~J. Yeager, P.~S. Powledge, A.~V. Mamishev, and J.~R. Smith,
  ``Design of an {RFID}-based battery-free programmable sensing platform,''
  \emph{{IEEE} Trans. Instrum. Meas.}, vol.~57, no.~11, pp. 2608--2615, Jun.
  2008.

\bibitem{assimonis2015sensitive}
S.~D. Assimonis, S.~N. Daskalakis, and A.~Bletsas, ``Sensitive and efficient
  {RF} harvesting supply for batteryless backscatter sensor networks,''
  \emph{{IEEE} Trans. Microw. Theory Techn.}, vol.~64, no.~4, pp. 1327--1338,
  Apr. 2016.

\bibitem{daskalakis2016soil}
S.~N. Daskalakis, S.~D. Assimonis, E.~Kampianakis, and A.~Bletsas, ``Soil
  moisture scatter radio networking with low power,'' \emph{{IEEE} Trans.
  Microw. Theory Techn.}, vol.~64, no.~7, pp. 2338--2346, Jun. 2016.

\bibitem{kampianakis2014wireless}
E.~Kampianakis, J.~Kimionis, K.~Tountas, C.~Konstantopoulos, E.~Koutroulis, and
  A.~Bletsas, ``Wireless environmental sensor networking with analog scatter
  radio and timer principles,'' \emph{{IEEE} Sensors J.}, vol.~14, no.~10, pp.
  3365--3376, Oct. 2014.

\bibitem{konstantopoulosconverting}
C.~Konstantopoulos, E.~Koutroulis, N.~Mitianoudis, and A.~Bletsas, ``Converting
  a plant to a battery and wireless sensor with scatter radio and ultra-low
  cost,'' \emph{{IEEE} Trans. Instrum. Meas.}, vol.~65, no.~2, pp. 388--398,
  Feb. 2016.

\bibitem{pichorim2018two}
S.~F. Pichorim, N.~J. Gomes, and J.~C. Batchelor, ``Two solutions of soil
  moisture sensing with {RFID} for landslide monitoring,''
  \emph{Multidisciplinary Digital Publishing Institute Sensors J.}, vol.~18,
  no.~2, p. 452, 2018.

\bibitem{daskalakis2017backscatter}
S.~N. Daskalakis, A.~Collado, A.~Georgiadis, and M.~M. Tentzeris, ``Backscatter
  morse leaf sensor for agricultural wireless sensor networks,'' in \emph{Proc.
  {IEEE} Sensors Conf.}, Glasgow, UK, Oct. 2017, pp. 1--3.

\bibitem{fahie1884history}
J.~J. Fahie, \emph{A History of Electric Telegraphy, to the year 1837}.\hskip
  1em plus 0.5em minus 0.4em\relax London: E. \& FN Spon, 1884.

\bibitem{proakis2008digital}
J.~G. Proakis and M.~Salehi, \emph{Digital Communications fifth edition,
  2007}.\hskip 1em plus 0.5em minus 0.4em\relax McGraw-Hill Companies, Inc.,
  New York, NY, 2008.

\bibitem{PIC16LF1459}
\BIBentryALTinterwordspacing
\emph{{PIC16LF1459}, {USB} Microcontroller with Extreme Low-Power Technology,
  product manual}, {M}icrochip {T}echnology {I}nc., 2014. [Online]. Available:
  \url{http://www.microchip.com/downloads/en/DeviceDoc/40001639B.pdf}
\BIBentrySTDinterwordspacing

\bibitem{TS3002}
\BIBentryALTinterwordspacing
\emph{TS3002 1V/1uA Easy-to-Use Silicon Oscillator/Timer, product manual},
  Silicon Laboratories, Inc., 2014. [Online]. Available:
  \url{https://docs-apac.rs-online.com/webdocs/1257/0900766b812571eb.pdf}
\BIBentrySTDinterwordspacing

\bibitem{XC6504}
\BIBentryALTinterwordspacing
\emph{{XC6504} Ultra Low Power Consumption Voltage Regulator, product manual},
  {U}orex {S}emiconductor, 2012. [Online]. Available:
  \url{https://www.torexsemi.com/file/xc6504/XC6504.pdf}
\BIBentrySTDinterwordspacing

\bibitem{KonstantopoulosMSc}
C.~Konstantopoulos, ``Self-{P}owered {P}lant {S}ensor for {S}catter {R}adio,''
  Master's thesis, School of Electrical and Computer Engineering, Technical
  University of Crete, Greece, 2015.

\bibitem{instrumentsTPL5010}
\BIBentryALTinterwordspacing
\emph{{TPL5010} Nano-power System Timer with Watchdog Function, product
  manual}, {I}nstruments, {T}exas, 2015. [Online]. Available:
  \url{http://www.ti.com/lit/ds/symlink/tpl5010.pdf}
\BIBentrySTDinterwordspacing

\bibitem{instrumentsLMT84}
\BIBentryALTinterwordspacing
\emph{{LMT84} Analog Temperature Sensor, product manual}, {I}nstruments,
  {T}exas, 2017. [Online]. Available:
  \url{http://www.ti.com/lit/ds/symlink/lmt84.pdf}
\BIBentrySTDinterwordspacing

\bibitem{ADG919}
\BIBentryALTinterwordspacing
\emph{ADG919 RF switch, product manual, product manual}, {A}nalog {D}evices,
  2016. [Online]. Available:
  \url{http://www.analog.com/media/en/technical-documentation/data-sheets/ADG918\_919.pdf}
\BIBentrySTDinterwordspacing

\bibitem{niotaki2014solar}
K.~Niotaki, A.~Collado, A.~Georgiadis, S.~Kim, and M.~M. Tentzeris,
  ``Solar/{E}lectromagnetic energy harvesting and wireless power
  transmission,'' \emph{Proc. {IEEE}}, vol. 102, no.~11, pp. 1712--1722, Nov.
  2014.

\bibitem{SP3-37}
\BIBentryALTinterwordspacing
\emph{{SP3-37} {F}lexible {S}olar {P}anel 3{V} @ 22mA, product manual},
  {P}owerFilm, 2009. [Online]. Available: \url{https://goo.gl/q5ECXh}
\BIBentrySTDinterwordspacing

\bibitem{NESDR}
\BIBentryALTinterwordspacing
\emph{{NESDR} {SMA}rt {B}undle-Premium {RTL-SDR}, product manual}, Noo{E}lec
  {I}nc., 2017. [Online]. Available:
  \url{http://www.nooelec.com/store/nesdr-smart.html}
\BIBentrySTDinterwordspacing

\bibitem{radio2007gnu}
G.~Radio, ``The gnu software radio,'' \emph{Available from World Wide Web:
  https://gnuradio. org}, 2007.

\bibitem{baronti2007wireless}
P.~Baronti, P.~Pillai, V.~W. Chook, S.~Chessa, A.~Gotta, and Y.~F. Hu,
  ``Wireless sensor networks: A survey on the state of the art and the 802.15.4
  and {Z}igbee standards,'' \emph{Elsevier, Computer Communications}, vol.~30,
  no.~7, pp. 1655--1695, May. 2007.

\end{thebibliography}

%\vfill
\end{document}

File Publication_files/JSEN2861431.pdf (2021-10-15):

# IEEE Proof

IEEE SENSORS JOURNAL

# A uW Backscatter-Morse-Leaf Sensor for Low-Power Agricultural Wireless Sensor Networks

Spyridon Nektarios Daskalakis , Student Member, IEEE, George Goussetis, Senior Member, IEEE, Stylianos D. Assimonis, Manos M. Tentzeris , Fellow, IEEE, and Apostolos Georgiadis , Senior Member, IEEE

Abstract— Nowadays, the monitoring of plant water stress is of high importance in smart agriculture. Instead of the traditional ground soil-moisture measurement, the leaf sensing is a new technology, which is used for the detection of plants needing water. In this paper, a novel, low-cost, and low-power system for leaf sensing using a new plant backscatter sensor node/tag is presented. The latter, can result in the prevention of water waste (water-use efficiency), when is connected to an irrigation system. Specifically, the sensor measures the temperature differential between the leaf and the air, which is directly related to the plant water stress. Next, the tag collects the information from the leaf sensor through an analog-to-digital converter, and then, communicates remotely with a low-cost software-defined radio reader using monostatic backscatter architecture. The tag consists of the sensor board, a microcontroller, an external timer, and an RF front-end for communication. The timer produces a subcarrier frequency for simultaneous access of multiple tags. The proposed work could be scaled and be a part of a large backscatter wireless sensor network. The communication protocol exploits the low-complexity Morse code modulation on a 868 MHz carrier signal. The presented novel proof-of-consent prototype is batteryless and was powered by a flexible solar panel consuming power around 20 µW. The performance was validated in an indoors environment where wireless communication was successfully achieved up to 2 m distance.

Index Terms— Backscatter sensor networks, environmental monitoring, Internet-of-Things (IoT), leaf sensor, Morse code, precision agriculture, radio frequency identification (RFID) sensors, software-defined radio (SDR).

Manuscript received March 30, 2018; revised July 12, 2018; accepted
AQ:1 | July 18, 2018. This work was supported in part by the Lloyd’s Reg-
| ister Foundation (LRF) and in part by the International Consortium in
| Nanotechnology (ICON). The work of M. M. Tentzeris was supported
| in part by the National Science Foundation (NSF) and in part by the
| Defense Threat Reduction Agency (DTRA). This paper was presented at
| the IEEE Sensors Conference, Glasgow, U.K., October 29–November 1,
| 2017. The associate editor coordinating the review of this paper and approv-
| ing it for publication was Dr. Robert Roberts. (Corresponding author:
| Spyridon Nektarios Daskalakis.)
S. N. Daskalakis, G. Goussetis, and A. Georgiadis are with the School of
| Engineering and Physical Sciences, Institute of Sensors, Signals and Systems,
| Heriot-Watt University, Edinburgh EH14 4AS, U.K. (e-mail: sd70@hw.ac.uk;
| g.goussetis@hw.ac.uk; apostolos.georgiadis@ieee.org).
S. D. Assimonis is with the School of Electronics, Electrical Engineering
| and Computer Science, Queen’s University Belfast, Belfast BT3 9DT, U.K.
| (e-mail: s.assimonis@qub.ac.uk).
M. M. Tentzeris is with the School of Electrical and Computer Engineer-
| ing, Georgia Institute of Technology, Atlanta, GA 30332-250 USA (e-mail:
| etentze@ece.gatech.edu).
| Digital Object Identifier 10.1109/JSEN.2018.2861431
I. INTRODUCTION
PRECISION agriculture allows farmers to maximize yields using minimal resources such as water, fertilizer, pesti-cides and seeds. By deploying sensors and monitoring fields, farmers can manage their crops at micro scale [1]. This is also useful in order to predict diseases, conserve the resources and reduce the impacts of the environment. During the 1990s, early precision agriculture users adopted crop yield monitoring to generate fertilizer and pH correction recommendations. As more variables could be measured by sensors and were introduced into a crop model, more accurate recommendations could be made. The combination of the aforementioned sys-tems with wireless sensor networks (WSNs) allows multiple unassisted embedded devices (sensor nodes) to transmit wire-lessly data to central base stations [2], [3]. The base stations are able to store the data into cloud databases for worldwide processing and visualization [4]. Data (e.g., temperature, humidity, pressure) are collected from different on-board phys-ical sensors: dielectric soil moisture sensors, for instance, are widespread for moisture measurements, since they can estimate the moisture levels through the dielectric constant of the soil, which changes as the soil moisture is changing. Leaf sensing is an another way to measure the water status of a plant. When compared to soil moisture sensors, they can provide more accurate data since the measurements are directly taken on the plant and not through the soil or the atmosphere (air), which surround the latter [5]. Commercial leaf sensors are involve phytometric devices that measure the water deficit stress (WDS) by monitoring the moisture level in plant leaves. In recent work [6], a leaf sensor is used to measure the plant’s leaf thickness in order to determine the WDS. The sensor is provided by AgriHouse Inc. and it is suitable for real-time monitoring in aeroponics, hydroponics and drip irrigation systems [7]. In an extreme WDS scenario, the leaf thickness decreased dramatically (by as much as 45%) within a short period of time (2 hours). On other occasions, the leaf thickness was kept fairly constant for several days, but decreased substantially when WDS became too severe for the plant [6]. Despite such favourable features, this class of sensors can only be used in controlled environments (i.e., greenhouses) in combination with other type of sensors.

1558-1748 © 2018 IEEE. Personal use is permitted, but republication/redistribution requires IEEE permission. See http://www.ieee.org/publications_standards/publications/rights/index.html for more information.

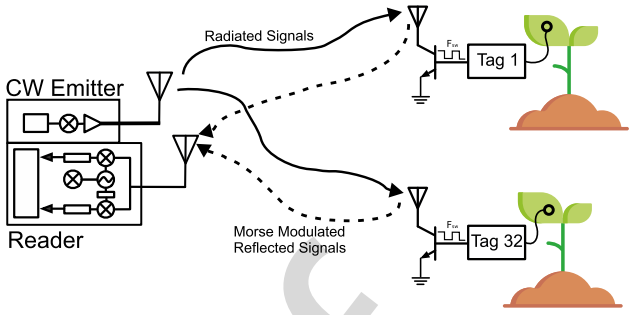
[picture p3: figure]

# IEEE Proof

2 | IEEE SENSORS JOURNAL
71 | This is because a direct relationship seems to exist between
72 | leaf thickness and the relative humidity of the ambient air,
73 | temperature, soil temperature and soil salinity [6].
74 | A different type of leaf sensor for WDS monitoring,
75 | is described in [5] and is using two temperature sensors. The
76 | monitoring is based on the temperature difference between the
77 | leaf and the air (Tleaf − Tair). This difference is strictly related
78 | to the plant water stress and can be used as decision parameter
79 | in a local irrigation system [8]. The first sensor measures the
80 | canopy temperature on the leaf (Tleaf) and the second the
81 | atmospheric temperature (Tair). The use of canopy temperature
82 | as an indicator of crop water stress has been the subject of
83 | much research over the past 30 years [9]. Canopy tempera-
84 | ture and water stress are related: when the soil moisture is
85 | reduced, stomatal closure occurs on the leaves resulting to
86 | reduced transpirational cooling. The canopy temperature is
87 | then increased above that of the air [10]. In a plant with ade-
88 | quate water supply, the term Tleaf−Tair will be zero or negative,
89 | but when the available water is limited, the difference will
90 | be positive.
91 | The leaf sensors that were described above are different
92 | from the well known leaf wetness sensors (LWS). The LWS
93 | can detect the leaf wetness which is a meteorological para-
94 | meter that describes the amount of dew and precipitation left
95 | on leaf surfaces. Leaf wetness can result from dew, fog, rain,
96 | and overhead irrigation. Today, the LWS are used most for
97 | disease-warning systems [11] and provided by companies like
98 | Davis Instruments Inc. and Meter Environment Inc. [12].
99 | The agricultural applications frequently involve large,
100 | expansive areas where wire connection for communication and
101 | power is undesirable or impracticable [2]. The high-cost and
102 | the high-power requirements of the today WSN hardware pre-
103 | vent its usage in agriculture. The deployment of these systems
104 | therefore relies on reducing the cost to an affordable amount.
105 | Capital expenditure relates to the cost of the hardware, which
106 | should therefore be maintained minimum. Energy autonomy
107 | for the sensor achieved by a combination of minimizing power
108 | consumption and harvesting ambient energy is likewise critical
109 | in order to reduce operational costs. Above factors drive the
110 | demand for low-cost, low-power WSN systems.
111 | Backscatter radio communication (i.e., reflection and mod-
112 | ulation of an incident radio frequency carrier) in combination
113 | with the use of energy assisted (or not) sensor tags is a method
114 | that addresses aforementioned constraints. It is used in radio
115 | frequency identification (RFID) applications and offers ultra-
116 | low-power and low-cost aspects [13]. The wireless communi-
117 | cation part of each tag can be simplified into a single radio
118 | frequency (RF) transistor and an antenna, which can be
119 | used for each sensor tag to send information to a base
120 | station (reader). It is a very energy-efficient communica-
121 | tion technique thus the RF signal is used not only for the
122 | communication, but also, for the power of the tag [14].
123 | In the recent literature, backscatter WSNs for smart agriculture
124 | purposes [15]–[18] were proposed. In [15] and [16], soil
125 | moisture and humidity sensors were proposed. A proof of
126 | concept demonstration was presented where the tags send
127 | measurements to a software-defined radio (SDR) reader. The
128 | WSNs employ semi-passive tags in bistatic topology and each
Fig. 1. | Monostatic backscatter communication setup. Plant sensing is
achieved by the tags and the information is sent back to a low-cost reader. Information is modulated using Morse coding on a 868 MHz radiated carrier.
backscatter sensor tag has power consumption of the order | 129
of 1 mW. The achieved communication range (tag-reader | 130
distance) is of the order of 100 m; this is achieved by sup- | 131
plying the tags with small batteries thereby enabling increased | 132
communication range. In [17], electric potential (EP) signals | 133
of plants can be measured by the tag in order to estimate when | 134
the plant needs water; in this work, the tags are batteryless and | 135
they harvest energy from the plant itself. In [18] two UHF | 136
RFID sensor nodes for soil moisture sensing were designed | 137
based on conventional RFID chips. | 138
This work discusses the implementation of a low-cost and | 139
low-power wireless sensor system for agricultural applications, | 140
which uses a novel plant, backscatter sensor node/tag. Pre- | 141
liminary results on this sensor node were proposed in [19]. | 142
The tag is connected with a temperature leaf sensor board | 143
for WDS measurements and reflects RF signals from a carrier | 144
emitter. It is noted that the proposed system can be a part of | 145
a backscatter WSN, transmitting data to a reader as shown | 146
in Fig. 1. Specifically the tag architecture consists of a micro- | 147
controller (MCU) and an external timer for the modulation. | 148
There is also a sensor board for the measurements and an FR | 149
front-end for the backscatter communication. The tag reads the | 150
information from the sensors and generates pulses that control | 151
an RF switch. | 152
The low complexity Morse code technique was selected for | 153
the backscatter modulation and it is the first time that Morse | 154
code is used in a backscatter WSN system. Morse code uses | 155
On-Off-Keying (OOK) modulation which means that a fre- | 156
quency signal exists in only two states either “On” or “Off”. | 157
Morse code and OOK contribute to architectural and power | 158
consumption efficiencies for the tag. A low-cost SDR is used | 159
as reader and collects the signals for further processing. The | 160
868 MHz in the European RFID band was selected as carrier | 161
emitter frequency. | 162
The structure of the this paper is as follows: Section II | 163
provides the basic principles of backscatter communication | 164
and the Morse encoding. In Section III the design and the | 165
implementation of the tag is described. Section IV discusses | 166
the hardware and software part of the low-cost receiver. | 167
Section V presents the proof-of-concept experimental setup | 168
and a communication indoor demo. In Section VI, the ben- | 169
efits of our proposed low-power WSN and future work are | 170
discussed. Finally, section VII includes concluding remarks. | 171

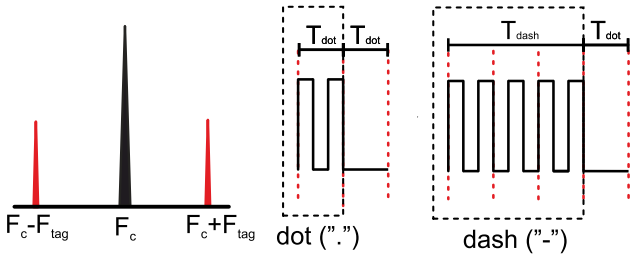
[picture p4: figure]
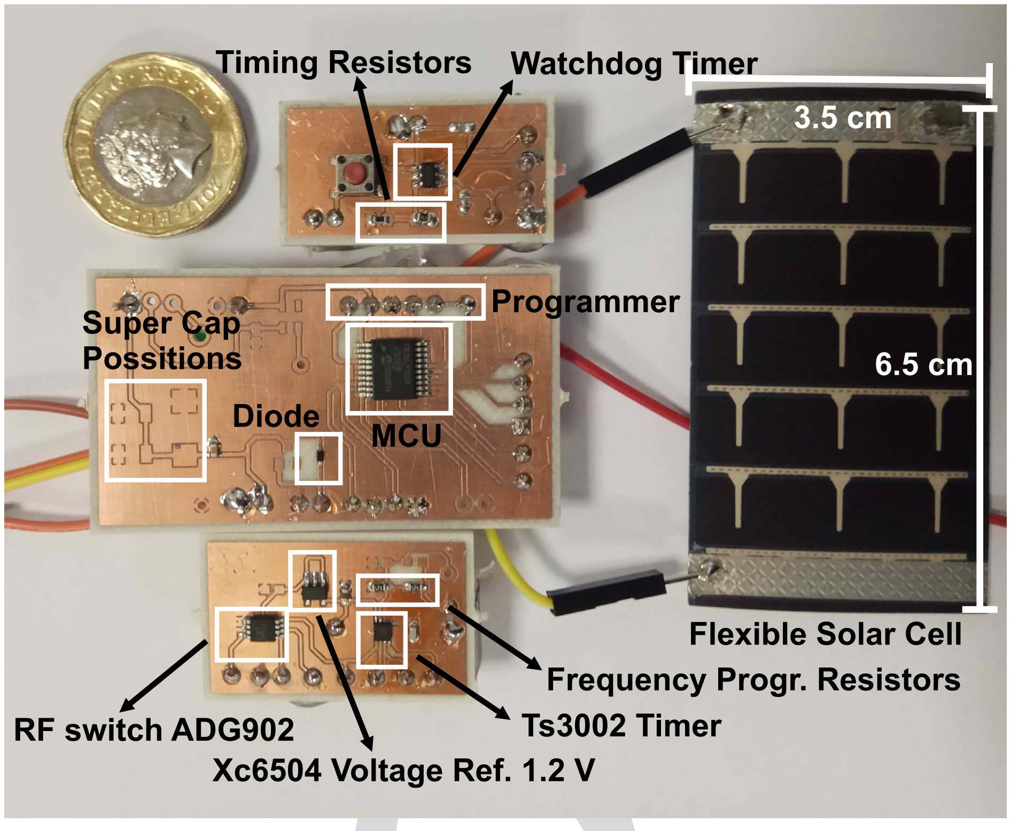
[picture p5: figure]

# IEEE Proof

DASKALAKIS et al.: uW BACKSCATTER-MORSE-LEAF SENSOR FOR LOW-POWER AGRICULTURAL WIRELESS SENSOR NETWORKS | 3
Fig. 2. | Left: In Backscatter principle when a Fc carrier exists and the RF
switch frequency is Ftag, two subcarriers appear with frequencies Fc ± Ftag. Right: Morse code symbols.
172 | II. BACKSCATTER AND MORSE ENCODING
173 | A typical backscatter communication system requires three
174 | devices: a tag, an emitter and a reader. Traditional batteryless
175 | RFID systems utilize monostatic architectures, where the
176 | reader and the emitter are in the same box. In this work this
177 | architecture is employed; the emitter transmits a continuous
178 | wave (CW) signal at frequency Fc = 868 MHz. The tag
179 | receives and scatters a fraction of it back to the reader as
180 | shown in Fig. 1. The backscatter binary communication can
181 | be implemented on the tag using an RF switch, an antenna
182 | and a control unit. The switch alternates the load of the
183 | antenna between two values (Z1/2) and offers two reflection
184 | coefficients, (-
1/2), according to

1/2 = Z1/2 − Z∗
a
Z1/2 + Za
185 | , | (1)
186 | with Za, the antenna impedance equal with 50 Ohm. When
187 | the CW with frequency Fc arrives on the antenna and the RF
188 | switch frequency is Ftag, frequency modulation occurs and two
189 | subcarriers appear in the spectrum with frequencies Fsub1/2 =
190 | Fc ± Ftag. The reflected signal (subcarriers) and the carrier are
191 | depicted in Fig. 2 (left). The subcarriers are next modulated
192 | using the Morse code scheme as it is described below.
193 | Morse code is a method of transmitting text information
194 | as a series of On-Off tones, named after the inventor of the
195 | telegraph Samuel F. B. Morse in the 1830s [20]. It is referred
196 | as the earliest type of binary digital communications since the
197 | code is made solely from ones and zeros (“On” and “Off”).
198 | Each letter of the alphabet is translated to combinations of
199 | dots “.” and dashes “-” that are sent over telegraph wires or by
200 | radio waves from one place to another. For example, the
201 | letter “A” is translated to the sequence “.-” with elements
202 | one dot and one dash symbol. Lets assume that the duration
203 | of a dot (Tdot) is one unit, then the duration a dash is three
204 | units (3Tdot). Dot and dash symbols are followed by a short
205 | silence, equal to one unit (Fig. 2, right). The space between the
206 | elements of one letter/character is one unit, between characters
207 | is three units and between words, seven units.
208 | The Morse code is the only digital modulation designed to
209 | be easily read without a computer. Today it is usually used by
210 | radio amateurs and it is the fist time that is used in backscatter
211 | communication. The OOK modulation is used to transmit
212 | Morse code signals over a fixed radio frequency. The OOK is
213 | a simplest form of amplitude-shift keying (ASK) modulation
214 | that can represent digital data using a presence (“On”) or an
Fig. 3. | Printed circuit boards of the tag and the solar cell. The watchdog
timer (top) and the timer module (bottom) are connected with the main processor unit in the middle.
absence (“Off”) of a carrier signal. With OOK modulation | 215
and thus Morse code, the complexity of the receiver and | 216
the tag is drastically simplified compared to a frequency | 217
modulation (FM) scheme thus there is no need for a differ- | 218
ent frequency for each symbol [21]. Also, Morse code was | 219
designed so that the most frequently used letters have the | 220
shortest codes. In general, code length increases as frequency | 221
decreases. | 222
In this work the “.” (dot of Morse code) is implemented as | 223
a signal with a specific duration Tdot and frequency Ftag. As it | 224
is expected the “-” (dash in Morse code) is then implemented | 225
using a signal of the same frequency with duration equal to | 226
three times that of the dot signal. The Tdot is defined by the | 227
MCU and the Ftag is defined by the external timer of the tag. | 228
The dot and dash frequency signals are shown in Fig. 2 (left). | 229
The speed of Morse code is stated in words per minute (WPM) | 230
and according to the standards, the word PARIS is used to | 231
determine it. The word is translated to exactly 50 units and | 232
one dot duration is defined by the formula: Tdot = 1200/WPM | 233
with Tdot in ms. | 234
III. TAG IMPLEMENTATION | 235
A. Main Unit | 236
The proof-of-concept tag consists of five different parts | 237
implemented in different printed circuit boards (PCBs) for | 238
simplifying debugging. These parts are the MCU unit, | 239
the timer part, the watchdog timer part, the sensor board, | 240
and finally the RF front-end. The MCU unit (Fig. 3, middle) | 241
is the main part of the system and it is responsible for the | 242
data sensor acquisition, the implementation of the Morse code | 243
symbols and the control of the other parts. The schematic of | 244
the main system is depicted in Fig. 4. The ultra-low-power | 245
8-bit PIC16LF1459 from Microchip with current consumption | 246
of only 25 μA/MHz at 1.8 V [22] was selected for the | 247
MCU. The MCU collects data from the sensor board using | 248
the embedded analog-to-digital converter (ADC) with 10-bit | 249
resolution. It contains also a digital-to-analog converter (DAC) | 250
with 5-bit resolution. The internal 31 kHz low-power oscillator | 251

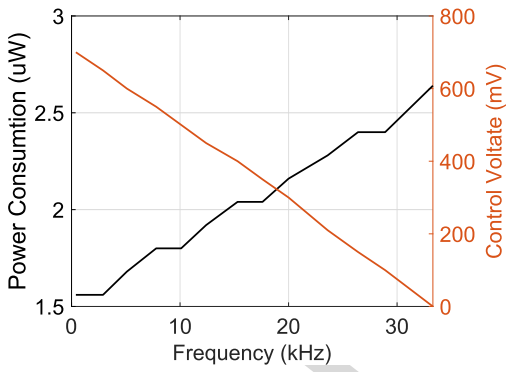
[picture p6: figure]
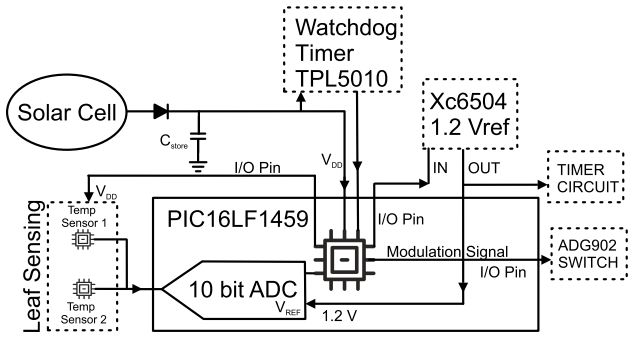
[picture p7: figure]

# IEEE Proof

4 | IEEE SENSORS JOURNAL

Fig. 4. The schematic of the tag’s main unit. The main part, is a low-power MCU that controls the sensors, the timer and the RF front-end.

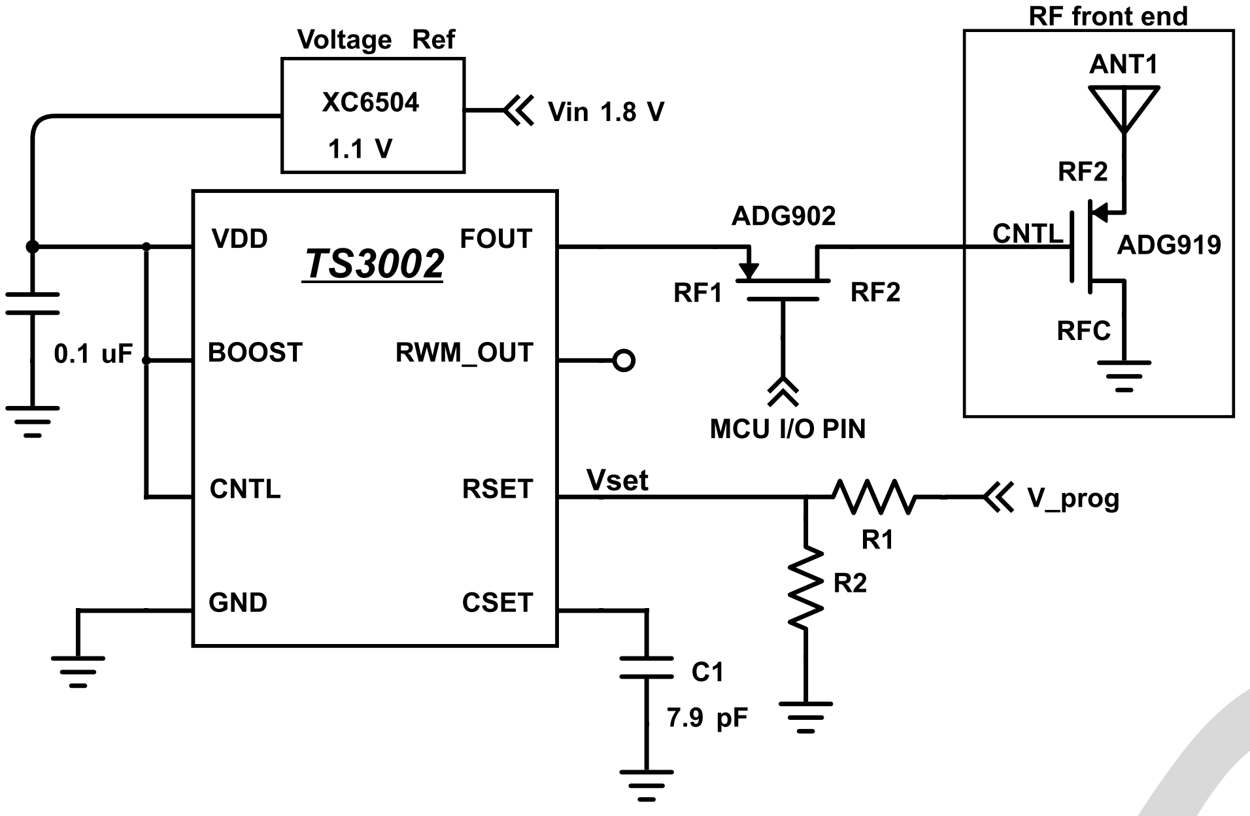
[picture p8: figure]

Fig. 5. Timer and RF front-end schematic of the tag. The timer produces square wave pulses with 50% duty circle and supplies the RF front-end through a modulation switch (ADG902). The ADG902 switch is controlled by the MCU.

252 | was utilized as clock source in order to reduce the power
253 | consumption of the tag. The MCU is responsible to supply all
254 | the other parts with voltage when it is necessary. The main part
255 | is connected with a μW timer for the subcarrier signal (Ftag)
256 | production and an external watchdog timer to wake up the
257 | MCU from the “sleep” operation mode. In sleep mode the
258 | MCU current consumption was only 0.6 μA at 1.8 V.
259 | B. Timers
260 | The timer module (Fig. 3, bottom) consists of a very
261 | low-power timer (TS3002), a voltage reference and a switch.
262 | It is responsible for producing the subcarrier frequency of the
263 | tag Ftag and modulating this subcarrier through the switch. The
264 | low-power, single-pole single-throw (SPST) switch ADG902
265 | was used in this case and one of the MCU input/output (I/O)
266 | pins was programmed to provide the necessary Morse code
267 | pulses for the control. The implemented circuit is depicted
268 | in Fig. 5. The TS3002 is a CMOS oscillator provided by
269 | Silicon Labs Inc., fully specified to operate at around 1 V
270 | and to consume current lower than 5 μA with an output
271 | frequency range from 5.2 kHz to 290 kHz [23]. The timer
272 | was supplied by a voltage reference integrated circuit (IC)
273 | XC6504 at 1.2 V [24] in order to reduce the power consump-
274 | tion. XC6504 provides also stable reference voltage at the
275 | ADC of the tag and it is activated by an I/O pin of MCU.
276 | The output frequency of the timer is programmed by using
277 | two parallel external resistors, a capacitor and a voltage value.
Fig. 6. | Power consumption of the TS3002 timer versus the output
frequency (Ftag) versus the control voltage Vprog.
The square wave pulses have 50 % duty cycle and the | 278
maximum oscillation frequency when a zero voltage is applied | 279
at Vprog, is given by | 280
Ftag,max = | 1
1.19C1Rset
, | (2) | 281
with Rset = R1R2/(R1 + R2). In our proof-of-concept proto- | 282
type two identical resistors were used with value of 6.2 MOhm | 283
and tolerance 1% in order to avoid the frequency jitter. The | 284
output frequency was programmed to 34.3 kHz and the power | 285
consumption of the timer circuit was measured at 2.62 uW. | 286
The above measurement includes the power consumption of | 287
the voltage reference IC. The TS3002 can be configured as | 288
a voltage controlled oscillator (VCO) by applying a positive | 289
voltage value at Vprog terminal and the Ftag frequency is | 290
defined as [25]: | 291

Ftag = Vprog

−Ftag,max

Vprog,max

+ Ftag,max, | (3) | 292
with Vprog,max, the maximum value of Vprog when the timer | 293
gives zero frequency at its output. In Fig. 6 the ultra-low- | 294
power consumption of the timer versus different frequencies | 295
at the output is shown. Each frequency value corresponds to | 296
a different control voltage value (Vprog). | | 297
In case of a multiple access scheme, we have multiple tags | 298
in the same network sending information simultaneously. Each | 299
tag must operate in different Ftag frequency and the embedded | 300
DAC could be used in order to tune every tag in different | 301
subcarrier. The DAC can supply the timer with 2⁵ distinct | 302
voltage levels (Vprog) corresponding to 32 distinct subcarriers | 303
resulting in 32 tags in the same network. In this work the DAC | 304
is not used in order to reduce the overall power consumption of | 305
the prototype tag. The subcarrier frequency was programmed | 306
manually by using the two resistors and Vprog terminal was | 307
connected to the ground. | 308
For minimization of the average power consumption, a duty | 309
cycle operation of the tag was programmed. The tag was active | 310
only for a desired minimum period of time and a watchdog | 311
timer was used as a real-time clock (RTC). Specifically, | 312
the nano power TPL5010 timer from Texas Instruments [26] | 313
was utilized, which consumes only 35 nA. The timer can work | 314
as RTC and allows the MCU to be placed in sleep mode. | 315

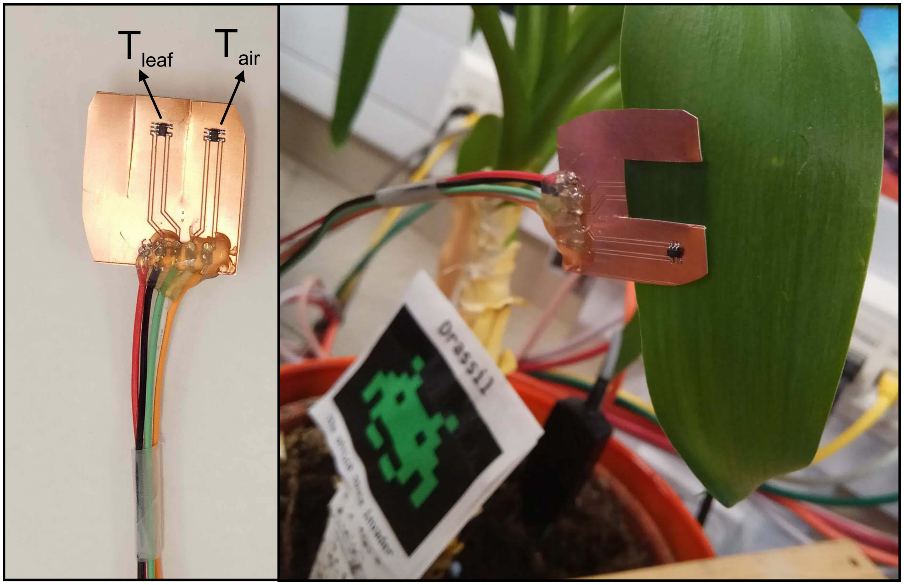
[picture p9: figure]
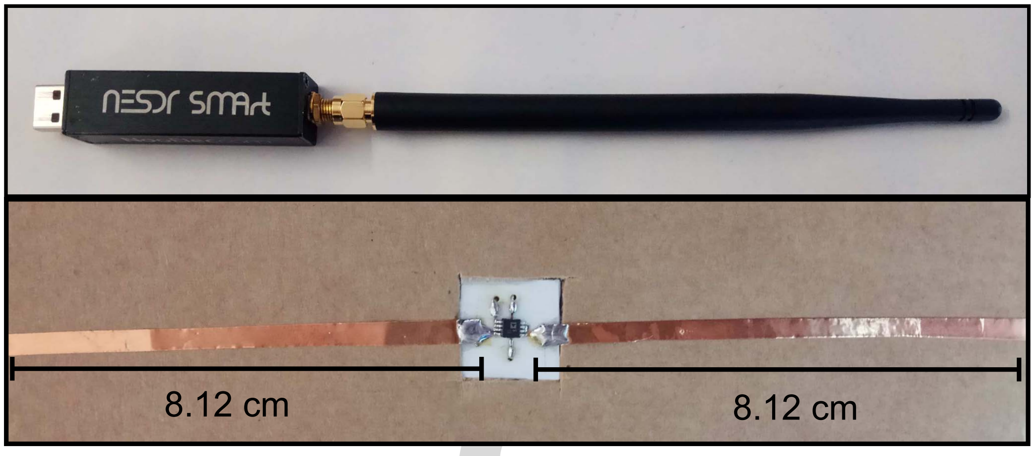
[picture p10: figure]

# IEEE Proof

DASKALAKIS et al.: uW BACKSCATTER-MORSE-LEAF SENSOR FOR LOW-POWER AGRICULTURAL WIRELESS SENSOR NETWORKS

Fig. 7. Printed circuit board with low-power LMT84 temperature sensors. The sensor board can be placed easily on a leaf.

The timer can provide an interrupt signal in selectable timing intervals from 0.1 to 7200 s by programming two external parallel resistors. It was programmed to wake up the MCU every 4 s activating the duty cycle operation of the system. The PCB of the watchdog timer is shown in Fig. 3 (top).

C. Sensor Board
The sensor board consists of two analog temperature sensors “LMT84” by Texas Instruments (Fig. 7, left). Each sensor is connected with an ADC input and consumes 5.4 μA at
1.8 V [27]. The accuracy of each one is ±0.4◦ 325 | C, while both
were placed on a “clip” scheme board in order to be easily mounted on a leaf. The prototype placed on a leaf is depicted in Fig. 7, (right). The temperature sensor seen on the top measures the air temperature (Tair), while a similar sensor under the leaf surface is placed in direct contact with the
leaf and measures the canopy temperature Tleaf ³³¹ | . The transfer
function of the each sensor is defined as [27]:
Tleaf/air = ⁵.506 − √36.445 − 0.00704Vleaf/air
−0.00352 ³³³ | + 30, (4)
where Vleaf/air is the ADC value in mV and Tleaf/air ³³⁴ | is tem-
perature in ◦ 335 | C. The MCU collects data from sensors one
by one in order to minimize the instantaneous power consumption. The two ADC measurements were encoded using the Morse code and were sent back to the receiver. At the receiver, the signal from both sensors is decoded in terms of a voltage value (in mV) and the temperature is then calculated using formula (4). Subsequently, the temperature difference
Tleaf − Tair ³⁴² | is estimated and recorded.
D. RF Front-End
The RF front-end part consists of an RF switch and a custom dipole antenna as it is depicted in Fig. 8 (bottom). The RF front-end is connected to the ADG902 switch of the timer module (Fig. 5). It is used for the wireless communication with the reader and it it responsible for creating the reflections of the incident CW signal. The single-pole, double-throw (SPDT) switch ADG919 [28] was selected due to its low insertion loss and high “OFF” isolation. The “RFC” and the “RF2” terminals of the RF switch were connected to the two arms of dipole antenna. The dipole antenna has omnidirectional

Fig. 8. Top: Low-cost software-defined radio. Bottom: RF front-end board

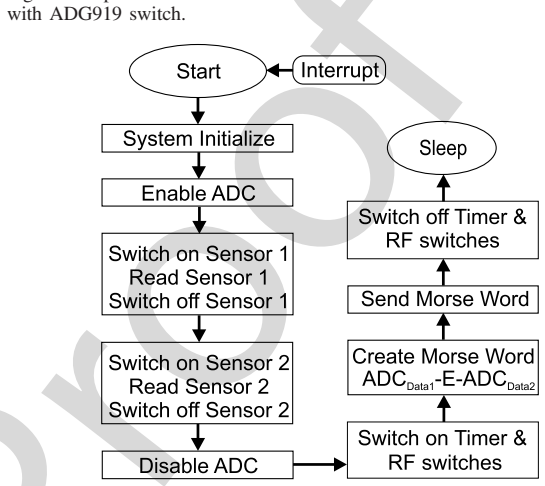
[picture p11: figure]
with ADG919 switch.

Fig. 9. Flow chart of the tag algorithm. This algorithm was implemented in the MCU and controls all the peripherals of the tag.

attributes at the vertical to its axis level and was designed for operation at 868 MHz. The bottom picture of Fig. 8 shows the fabricated prototype and the dimensions of the antenna. The RF Front-end was fabricated using copper tape on cardboard substrate.

E. Tag Analysis
In this work a solar panel harvester was employed for powering the tag. Solar energy could be used to power the tag also in combination with other energy harvesting technologies [29]. This solar module is the flexible, thin-film SP3-37 provided by PowerFilm Inc. [30]. The solar panel charges a 11 mF super capacitor (CPH3225A) instead of a battery through a low voltage drop Schottky diode. For the diode, the SMS7630-079LF by Skyworks Inc. with forward voltage drop only 150 mV was selected. The solar panel, the diode and the capacitor positions are depicted in Fig. 3. On the tag, a real-time algorithm was implemented in order to read the sensor information and wirelessly transmit it to the receiver. The steps of the algorithm are shown in Fig. 9. Initially, an interrupt signal coming from the watchdog timer is used to wake up the MCU. Next, initialization of the system (ADC, clock, I/O pins) is achieved and the ADC is enabled for data capture. The two temperature sensors are consecutively powered and the ADC reads the data from each one. The ADC is turned off immediately after this action for reducing the energy consumption. In the next step, the TS3002 timer and the ADG902/919 switches are switched

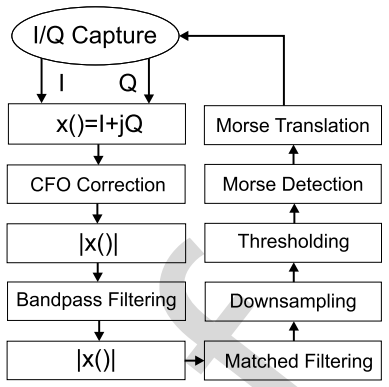
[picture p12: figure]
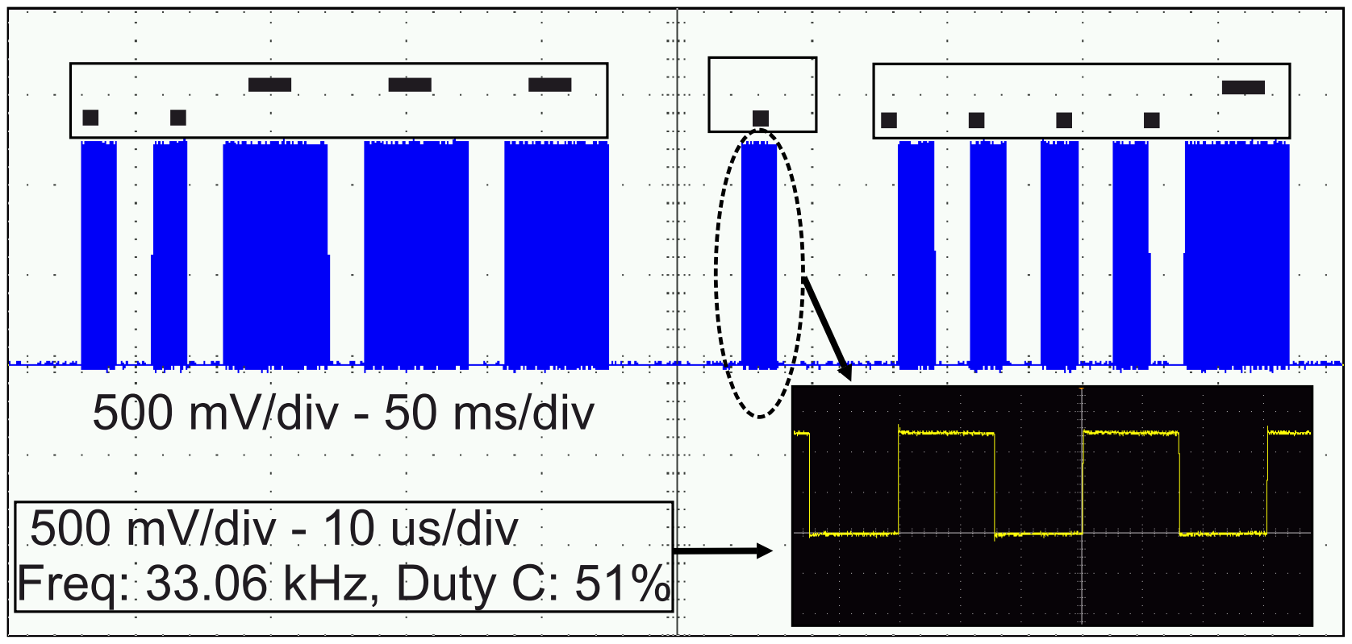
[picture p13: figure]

# IEEE Proof

IEEE SENSORS JOURNAL

Fig. 10. Oscilloscope measurement of a Morse coded word: “. . - - - | -”
corresponding to “2E4” word. This square wave signal is used to control the RF front-end.

on two steps before the data sending. This is necessary for the frequency stabilization of the timer. The tag was programmed to send a Morse coded word with fixed format every time the algorithm is running. The format of the word was defined as “ADCDATA1EADCDATA2” with ADCDATA1, ADCDATA2, the ADC values, varied for 0 to 1023. The sensor data were separated by the letter “E” and there are not any spaces between them. The goal was to create a short word to minimize the transmission time and thus the energy consumption. The letter “E” is the most common letter in English alphabet and has the shortest code, a single dot. The word is then translated in dots and dashes using the frequency Ftag of the timer and baseband pulses coming from the MCU.
The MCU produces baseband pulses that contain the dots, dashes and the spaces between them. This signal is coming from an I/O pin and is used to modulate the timer’s frequency signal through the ADG902 switch. In Fig. 10 an oscilloscope measurement of a modulated example signal at the output of ADG902 switch is shown. The depicted word is the “2E4”
400 | which is translated in “. . - - - | . | . . . . -”, while
each dot/dash is a 33 kHz signal with different duration. The required spaces between the Morse code symbols can also be observed. In order to send this word wirelessly, the RF switch ADG919 is fed with this signal and the incident CW carrier is modulated again by the tag information. In the last step of the algorithm, the switches and the timer were switched off and the tag goes to sleep mode. The time duration of the algorithm depends from the ADC data and the worst-case scenario is the word “1023E1023”. In that case the duration of the hole process lasts 2.8 s assuming 104.3 WPM speed.
| IV. RECEIVER
In our system the temperature ADC data are received by a low-cost SDR. This receiver is the “NESDR SMArt” SDR available by the NooElec Inc. (Fig. 8, top) [31]. It is an improved version of classic RTL SDR dongle based on the same RTL2832U demodulator with USB interface and R820T2 tuner. The tuning frequency range varies from 24 MHz to 1850 MHz with sampling rate up to 2.8 MS/s and noise figure about 3.5 dB. Gain control is also provided through the embedded low noise amplifier (LNA) at the input of R820T2, while at the output through a variable gain amplifier (VGA). It down-converts the received RF signal to baseband and it sends real (I) and imaginary (Q) signal

Fig. 11. Flow chart of the real-time receiver algorithm. The decoding algorithm was implemented in MATLAB software.

samples to a computer through an USB interface. All the above parameters make it suitable for our application also noting that the required sampling rate is quite low (250 kS/s) and it costs only 12.8 GBP. The receiver was connected with a 868 MHz monopole antenna to receive the signals from the tag.
A real-time algorithm was implemented in MATLAB in order to detect the reflected signals. The SDR can be con-nected with MATLAB through the open course GNU radio framework [32]. In the algorithm, the subcarrier frequency Ftag of the tag is known and the algorithm collects data in a window with duration: 2×length(maximum word). As shown in Fig. 11, the received I and Q digitized samples were combined together in complex numbers. Carrier frequency offset (CFO) was estimated and the signal was corrected. This accounts for the difference in carrier frequency between the SDR and the emitter, providing the variance between the real values and the estimated values of the subcarrier signal. The CFO was estimated after the samples were collected and then all samples were frequency shifted accordingly. The absolute value is taken and a bandpass filter with center frequency Ftag is applied in order to appear the Morse code word. After considering the signal magnitude, a matched filter was applied to appear the baseband Mode symbols. The matched filter is a square pulse with duration Tdot. The received signal of the Fig. 10 word is shown in Fig. 12, (a) after the Band-pass filtering. In Fig. 12, (b) is shown the above signal after matched filtering. The matched filtering was followed by downsampling with a factor of 100 for reducing of the computational complexity. Next, the received signal must be digitized using a threshold level. AGC (automatic gain control) and threshold decision is needed because the signal strength varies over time. The digitization procedure, which is using a suitable threshold, is depicted in Fig. 12, (c). The digitized signal was classified in order to detect the Morse code symbols and thus the alphabet characters. For the classification, a group of tokens was used with each token to be an English alphabet character translated in dots and dashes. The output of the algorithm is the English text and number representation of the Morse word.
V. EXPERIMENTAL RESULTS
The proof-of-concept system was tested indoors in a setup depicted in Fig. 13 in order to validate the effectiveness of

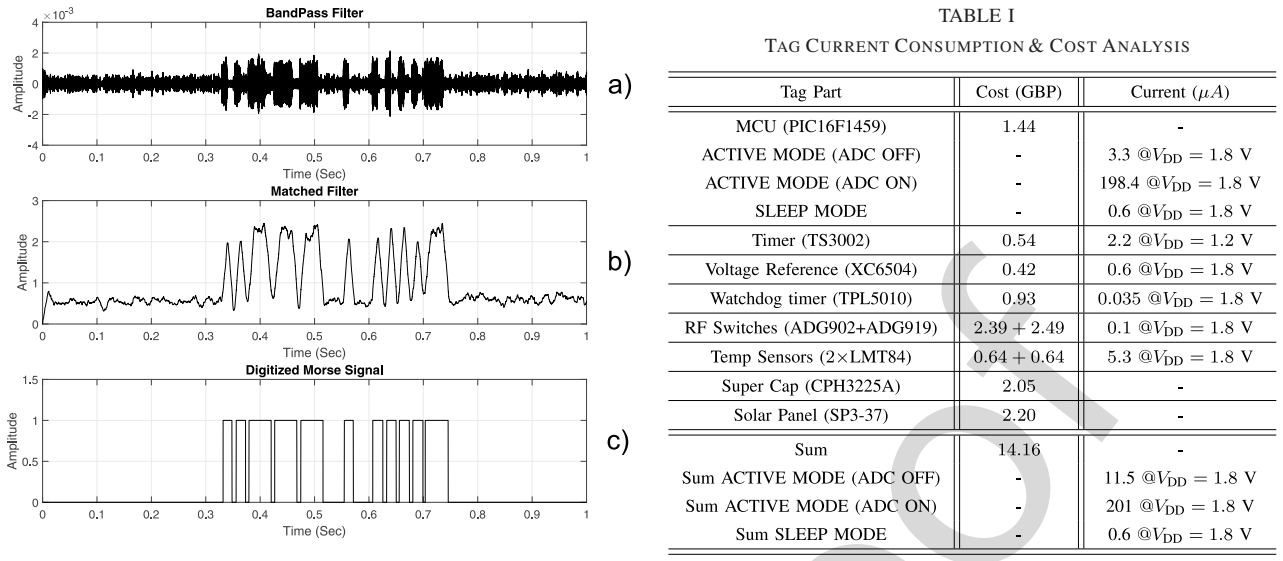
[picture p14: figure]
TABLE I; TAG CURRENT CONSUMPTION &COST ANALYSIS

# IEEE Proof

DASKALAKIS et al.: uW BACKSCATTER-MORSE-LEAF SENSOR FOR LOW-POWER AGRICULTURAL WIRELESS SENSOR NETWORKS | 7

Fig. 12. A received signal including a Morse coded word in three different steps of decoding algorithm.

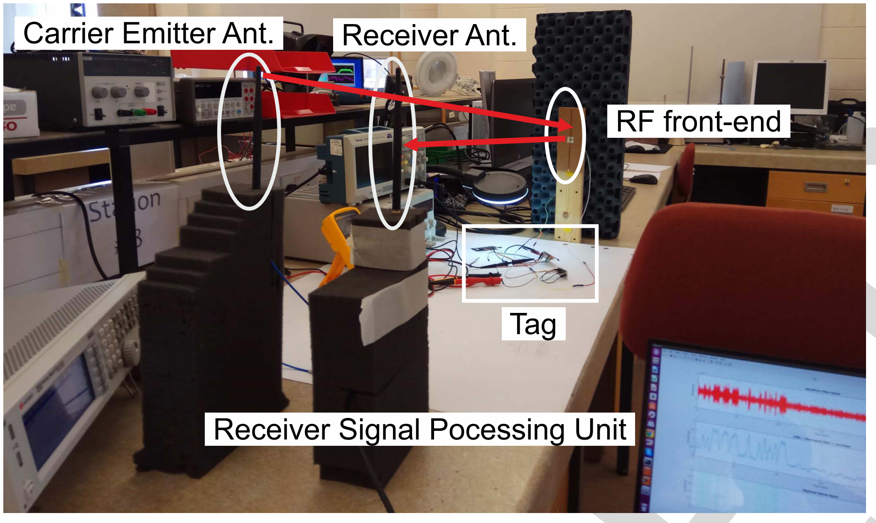
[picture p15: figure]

Fig. 13. Experimental indoor backscatter topology. The tag was measured in monostatic architecture 2 m away from emitter and receiver antennas.

466 | our backscatter communication system. The emitter, the tag
467 | and the reader were tested in monostatic architecture in
468 | Heriot-Watt University electromagnetics lab. A signal genera-
469 | tor with a monopole antenna was utilized as the CW emitter
470 | at 868 MHz, with a transmission power of 13 dBm. The SDR
471 | reader was used as the software-defined receiver in the same
472 | position with the emitter. The receiver was tuned to 868 MHz
473 | with sampling rate 250 kbps. The distance between the reader
474 | and emitter antenna was fixed at 17.27 cm (λ/2). The tag was
475 | placed 2 m away from the emitter/reader antennas and was
476 | programmed to produce words with Morse code symbols. Each
477 | word contains the Tleaf and Tair values in mV at 104.3 WPM
478 | speed. The sensor node has low-power consumption and was
479 | supplied by the solar panel and the super capacitor. An office
480 | lamb was used as an indoor source of light. Results shown that
481 | the transmitted words can be presented clearly at the receiver.
482 | Table I provides cost of the most significant components
483 | of the tag and the current consumption of each one. In active
484 | mode, the maximum overall dissipated current at 1.8 V was
485 | measured 11.5 μA (20.7 μW) when the ADC was off and
486 | 201 μA (362 μW) when the ADC was active. In the sleep
mode operation the current consumption was 0.6 μA (1 μW). | 487
Finally, using discrete electronic components in terms of bill | 488
of materials (BOM), the tag results in the cost of 14.1 GBP | 489
and the prices of each component were found from online | 490
suppliers on the order of one. | 491
Looking at the market, we found only one leaf sensor pro- | 492
vided by Agrihouse Inc. It costs 290 USD without the wireless | 493
communication equipment and according to the above, this | 494
work seems to be a promising low-cost alternative solution in | 495
order to monitor the WDS of the plans. | 496
VI. SYSTEM CONSIDERATIONS &FUTURE WORK | 497
The architecture of the proposed WSN could include many | 498
low-cost emitters/readers, installed in a field and around them, | 499
multiple, backscatter sensors can be spread. Working in cells | 500
that contain groups of tags, each tag can backscatter infor- | 501
mation to the receiver at a specific subcarrier frequency. The | 502
tags inside each cell will employ frequency-division-multiple- | 503
access (FDMA) scheme, whereas the emitters/readers could | 504
operate in a time-division-multiple-access (TDMA) scheme. | 505
Using the above concept the development of a backscatter | 506
sensor network, could include hundreds of low-cost tags. | 507
The classic WSN nodes utilize duty cycling operation in | 508
order to decrease the power consumption thus extending WSN | 509
lifetime. In this work, the tag was designed such that as low | 510
as possible power and the utilization of duty cycling could | 511
further decrease the required energy requirements. In [16] | 512
was demonstrated that the power consumption of a similar | 513
proposed backscatter WSN is lower than a ZigBee-type WSN. | 514
ZigBee sensors are based on IEEE 802.15.4 communication | 515
protocol and are widespread for wireless area networks with | 516
small digital radios [33]. | 517
Future work will focus on sensing and communication | 518
measurements and on further deceasing the overall cost of | 519
the sensor node. A future challenge is also to design an RF | 520
electromagnetic energy harvester to combine all the different | 521
forms of ambient energy availability. The communication | 522
range of the above deployment can be extended by the | 523

# IEEE Proof

IEEE SENSORS JOURNAL

following modifications. First, it is possible to use circular polarized and directive antennas instead on the monopoles at the receiver and the reader. The antennas would be designed and fabricated on the same substrate with a proper distance between them in order to maximize gain and keep mutual coupling between them at low level. With circular polarization the alignment between the reader/emitter antenna and the tag will have less effect. Secondly, the RF front-end dipole antenna could be replaced with a better gain antenna. This work is a first attempt to design a low-cost and low-power leaf sensor for agriculture and specific sensing plant measurements will be prepared in the future. The proposed sensor must be calibrated for different values on relative humidity and soil moisture for a specific type of plant. Finally, the cost of the tag can be reduced by replacement of the super capacitor and the solar panel with a cheaper option.

VII. CONCLUSION
In this paper a novel backscatter leaf sensing system for agricultural purposes was presented. Specifically, it includes a sensor for leaf canopy temperature measurements and it can be used for water stress measurements on plants. The sensor node has low-power consumption of only 20 μW and is supplied by a solar panel without need of battery. Morse code modulation was used for the wireless communication with a low-cost SDR receiver by backscattering RF signals from a carrier emitter. The proposed system is part of the backscatter WSN for agriculture with a small cost per sensor node. It is suitable for distributed monitoring of environmental parameters in largescale, precision agriculture applications.

ACKNOWLEDGMENT
The authors would like to thank Alexios Costouri and all members of the Microwave Lab, Heriot-Watt University, Edinburgh, U.K., for their help in various steps throughout this work.

REFERENCES

[1] S. Ivanov, K. Bhargava, and W. Donnelly, “Precision farming: Sensor analytics,” IEEE Intell. Syst., vol. 30, no. 4, pp. 76–80, Jul./Aug. 2015.
[2] L. Ruiz-Garcia, L. Lunadei, P. Barreiro, and I. Robla, “A review of wireless sensor technologies and applications in agriculture and food industry: State of the art and current trends,” Sensors, vol. 9, no. 6, pp. 4728–4750, 2009.
[3] C. Yu, Y. Cui, L. Zhang, and S. Yang, “Zigbee wireless sensor network in environmental monitoring applications,” in Proc. 5th Int. Conf. Wireless Commun., Netw. Mobile Comput. (WiCOM), Beijing, China, Sep. 2009, pp. 1–5.
[4] N. Fahmi, S. Huda, E. Prayitno, M. U. H. Al Rasyid, M. C. Roziqin, and M. U. Pamenang, “A prototype of monitoring precision agriculture system based on WSN,” in Proc. Int. Seminar Intell. Technol. Its Appl. (ISITIA), Surabaya, Indonesia, Aug. 2017, pp. 323–328.
[5] V. Palazzari, P. Mezzanotte, F. Alimenti, F. Fratini, G. Orecchini, and
L. Roselli, “Leaf compatible ‘eco-friendly’ temperature sensor clip for high density monitoring wireless networks,” Wireless Power Transf., vol. 4, no. 1, pp. 55–60, Mar. 2017.
[6] H.-D. Seelig, R. J. Stoner, and J. C. Linden, “Irrigation control of cowpea plants using the measurement of leaf thickness under greenhouse conditions,” Irrigation Sci., vol. 30, no. 4, pp. 247–257, Jul. 2012.
[7] AgriHouse Inc. (2017). SG-1000 Leaf Sensor. [Online]. Available: https://www.biocontrols.com/Leaf%20Sensor/SG-1000softwareV1.pdf
[8] N. Abraham, P. S. Hema, E. K. Saritha, and S. Subramannian, “Irrigation automation based on soil electrical conductivity and leaf temperature,” Agricult. Water Manage., vol. 45, no. 2, pp. 145–157, Jul. 2000.
[9] N. R. Patel, A. N. Mehta, and A. M. Shekh, “Canopy temperature and water stress quantificaiton in rainfed pigeonpea (Cajanus cajan (L.) Millsp.),” Agricult. Forest Meteorol., vol. 109, no. 3, pp. 223–232, Sep. 2001.
[10] R. W. Pearcy, O. Bjorkman, A. T. Harrison, and H. A. Mooney, Pho-tosynthetic Performance of Two Desert Species With C4 Photosynthesis in Death Valley, California, vol. 70. Washington, DC, USA: Carnegie Inst. Sci., 1971, pp. 540–550.
[11] G. Hornero, J. E. GaitÃ¡n-Pitre, E. Serrano-Finetti, O. Casas, and
R. Pallas-Areny, “A novel low-cost smart leaf wetness sensor,” Comput. Electron. Agricult., vol. 143, pp. 286–292, Dec. 2017.
[12] Decagon Devices, Inc. (2016). PHYTOS 31, Dielectric Leaf Wetness Sensor, Product Manual. [Online]. Available: http://library.metergroup.com/Manuals/10386_Leaf%20Wetness%20Sensor_Web.pdf
[13] A. P. Sample, D. J. Yeager, P. S. Powledge, A. V. Mamishev, and
J. R. Smith, “Design of an RFID-based battery-free programmable sensing platform,” IEEE Trans. Instrum. Meas., vol. 57, no. 11, pp. 2608–2615, Nov. 2008.
[14] S. D. Assimonis, S.-N. Daskalakis, and A. Bletsas, “Sensitive and effi-cient RF harvesting supply for batteryless backscatter sensor networks,” IEEE Trans. Microw. Theory Techn., vol. 64, no. 4, pp. 1327–1338, Apr. 2016.
[15] S.-N. Daskalakis, S. D. Assimonis, E. Kampianakis, and A. Bletsas, “Soil moisture scatter radio networking with low power,” IEEE Trans. Microw. Theory Techn., vol. 64, no. 7, pp. 2338–2346, Jun. 2016.
[16] E. Kampianakis, J. Kimionis, K. Tountas, C. Konstantopoulos,
E. Koutroulis, and A. Bletsas, “Wireless environmental sensor networking with analog scatter radio and timer principles,” IEEE Sensors J., vol. 14, no. 10, pp. 3365–3376, Oct. 2014.
[17] C. Konstantopoulos, E. Koutroulis, N. Mitianoudis, and A. Bletsas, “Converting a plant to a battery and wireless sensor with scatter radio and ultra-low cost,” IEEE Trans. Instrum. Meas., vol. 65, no. 2, pp. 388–398, Feb. 2016.
[18] S. F. Pichorim, N. J. Gomes, and J. C. Batchelor, “Two solutions of soil moisture sensing with RFID for landslide monitoring,” Sensors, vol. 18, no. 2, p. E452, 2018.
[19] S. N. Daskalakis, A. Collado, A. Georgiadis, and M. M. Tentzeris, “Backscatter morse leaf sensor for agricultural wireless sensor net-works,” in Proc. IEEE Sensors, Glasgow, U.K., Oct./Nov. 2017, pp. 1–3.
[20] J. J. Fahie, A History of Electric Telegraphy, to the Year 1837. London, U.K.: E. & FN Spon, 1884.
[21] J. Proakis and M. Salehi, Digital Communications, 5th ed. New York, NY, USA: McGraw-Hill, 2007.
[22] Microchip Technology Inc. (2014). PIC16LF1459, USB Micro-controller With Extreme Low-Power Technology, Product Manual.
[Online]. | Available: | http://www.microchip.com/downloads/en/ | 630
DeviceDoc/40001639B.pdf | 631 AQ:2
[23] Silicon Laboratories, Inc. (2014). TS3002 1V/1uA Easy-to-Use Silicon Oscillator/Timer, Product Manual. [Online]. Available: https://docs-apac.rs-online.com/webdocs/1257/0900766b812571eb.pdf
[24] Torex Semiconductor. (2012). XC6504 Ultra Low Power Con-sumption Voltage Regulator, Product Manual. [Online]. Available: https://www.torexsemi.com/file/xc6504/XC6504.pdf
[25] C. Konstantopoulos, “Self-powered plant sensor node for scatter radio,” M.S. thesis, School Elect. Comput. Eng., Technical Univ. Crete, Chania, Greece, 2015.
[26] Texas Instruments. (2015). TPL5010 Nano-Power System Timer With Watchdog Function, Product Manual. [Online]. Available: http://www.ti.com/lit/ds/symlink/tpl5010.pdf
[27] Texas Instruments. (2017). LMT84 Analog Temperature Sensor, Product Manual. [Online]. Available: http://www.ti.com/lit/ds/symlink/lmt84.pdf
[28] Analog Devices. (2016). ADG919 RF Switch, Product Manual, Product Manual. [Online]. Available: http://www.analog.com/media/en/technical-documentation/data-sheets/ADG918_919.pdf
[29] K. Niotaki, A. Collado, A. Georgiadis, S. Kim, and M. M. Tentzeris, “Solar/electromagnetic energy harvesting and wireless power transmis-sion,” Proc. IEEE, vol. 102, no. 11, pp. 1712–1722, Nov. 2014.
[30] PowerFilm Solar. (2009). SP3-37 Flexible Solar Panel 3V @ 22mA, Product Manual. [Online]. Available: https://goo.gl/q5ECXh
[31] NooElec Inc. (2017). NESDR SMArt Bundle-Premium RTL-SDR, Prod-uct Manual. [Online]. Available: http://www.nooelec.com/store/nesdr-smart.html
[32] G. Radio. (2017). The GNU Software Radio. [Online]. Available: https://gnuradio.org
[33] P. Baronti, P. Pillai, V. W. C. Chook, S. Chessa, A. Gotta, and
Y. F. Hu, “Wireless sensor networks: A survey on the state of the art and the 802.15.4 and ZigBee standards,” Comput. Commun., vol. 30, no. 7, pp. 1655–1695, May 2007.
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

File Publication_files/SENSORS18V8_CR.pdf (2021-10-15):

# A uW Backscatter-Morse-Leaf Sensor for Low-Power Agricultural Wireless Sensor Networks

Spyridon N. Daskalakis, Student Member, IEEE, George Goussetis, Senior Member, IEEE, Stylianos D. Assimonis, Manos M. Tentzeris, Fellow, IEEE and Apostolos Georgiadis, Senior Member, IEEE

Abstract—Nowadays, the monitoring of plant water stress is of high importance in smart agriculture. Instead of the traditional ground soil-moisture measurement, leaf sensing is a new technology, which is used for the detection of plants needing water. In this work, a novel, low-cost and low-power system for leaf sensing using a new plant backscatter sensor node/tag is presented. The latter, can result in the prevention of water waste (water-use efficiency), when is connected to an irrigation system. Specifically, the sensor measures the temperature differential between the leaf and the air, which is directly related to the plant water stress. Next, the tag collects the information from the leaf sensor through an analog-to-digital converter (ADC), and then, communicates remotely with a low-cost software-defined radio (SDR) reader using monostatic backscatter architecture. The tag consists of the sensor board, a microcontroller, an external timer and an RF front-end for communication. The timer produces a subcarrier frequency for simultaneous access of multiple tags. The proposed work could be scaled and be a part of a large backscatter wireless sensor network (WSN). The communication protocol exploits the low-complexity Morse code modulation on a 868 MHz carrier signal. The presented novel proof-of-consent prototype is batteryless and was powered by a flexible solar panel consuming power around 20 µW. The performance was validated in an indoors environment where wireless communication was successfully achieved up to 2 m distance.

Index Terms—Backscatter sensor networks, environmental monitoring, Internet-of-Things (IoT), leaf sensor, Morse code, precision agriculture, radio frequency identification (RFID) sensors, software-defined radio (SDR).

I. INTRODUCTION

Precision agriculture allows farmers to maximize yields using minimal resources such as water, fertilizer, pesticides and seeds. By deploying sensors and monitoring fields, farmers can manage their crops at micro scale [?]. This is also useful in
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

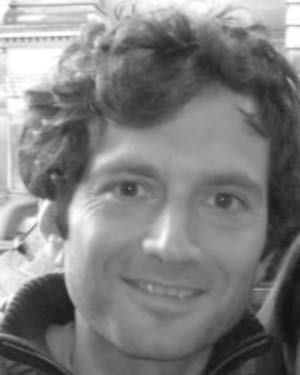
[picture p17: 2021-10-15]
Publication_files/Bios_Photos/Goussetis.jpg

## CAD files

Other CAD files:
Tag_files/Firmware/TAG_v4_Morse_1Mhz_opt/dist/default/production/TAG_v4_Morse_1Mhz_opt.production.obj
Tag_files/Firmware/TAG_v4_Morse_32KHz/dist/default/production/TAG_v4_Morse_32KHz.production.obj
Tag_files/Firmware/TAG_v5_Morse_32KHz_opt/dist/default/production/TAG_v5_Morse_32KHz_opt.production.obj
Tag_files/Firmware/TAG_v6_Morse_32KHz_time/dist/default/production/TAG_v6_Morse_32KHz_time.production.obj

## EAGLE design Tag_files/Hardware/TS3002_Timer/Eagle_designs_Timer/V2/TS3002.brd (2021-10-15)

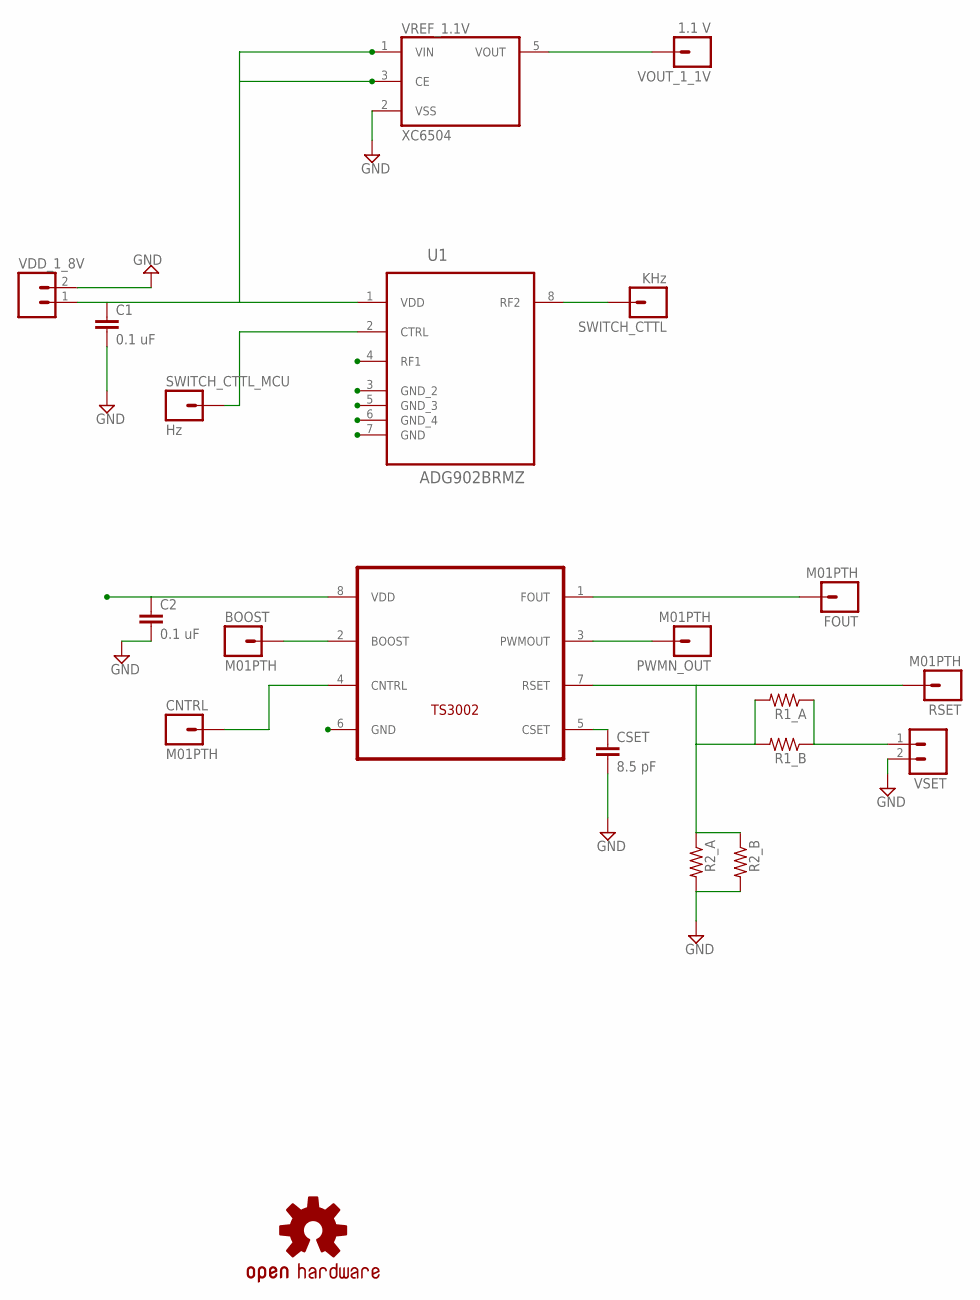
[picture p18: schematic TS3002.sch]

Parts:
BOOST: M01PTH; 1X01
C1, C2: 0.1 uF; 0603-CAP
CNTRL: M01PTH; 1X01
CSET: 8.5 pF; 0603-CAP
FOUT: M01PTH; 1X01
LOGO1: OSHW-LOGOL; OSHW-LOGO-L
PWMN_OUT: M01PTH; 1X01
R1_A, R1_B, R2_A, R2_B: RESISTOR0603-RES; 0603-RES
RSET: M01PTH; 1X01
SWITCH_CTTL: KHz; 1X01
SWITCH_CTTL_MCU: Hz; 1X01
U1: ADG902BRMZ; SOP65P490X110-8N
U$1: TS3002; TDFN22-8
VDD_1_8V: M02PTH; 1X02
VOUT_1_1V: 1.1 V; 1X01
VREF_1.1V: XC6504; SOT23-5
VSET: M02PTH; 1X02

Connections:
1_2OUT: C2.1, U$1.8 (VDD), VOUT_1_1V.1, VREF_1.1V.5 (VOUT)
GND: C1.2, C2.2, CSET.2, R2_A.2, R2_B.2, U1.3 (GND_2), U1.5 (GND_3), U1.6 (GND_4), U1.7 (GND), U$1.6 (GND), VDD_1_8V.2, VREF_1.1V.2 (VSS), VSET.2
unnamed: R1_A.1, R1_B.1, VSET.1
unnamed: SWITCH_CTTL_MCU.1, U1.2 (CTRL)
unnamed: BOOST.1, U$1.2 (BOOST)
unnamed: SWITCH_CTTL.1, U1.8 (RF2)
unnamed: CNTRL.1, U$1.4 (CNTRL)
unnamed: R1_A.2, R1_B.2, R2_A.1, R2_B.1, RSET.1, U$1.7 (RSET)
unnamed: PWMN_OUT.1, U$1.3 (PWMOUT)
unnamed: CSET.1, U$1.5 (CSET)
TIMER: FOUT.1, U1.4 (RF1), U$1.1 (FOUT)
VDD_1.8V1: C1.1, U1.1 (VDD), VDD_1_8V.1, VREF_1.1V.1 (VIN), VREF_1.1V.3 (CE)

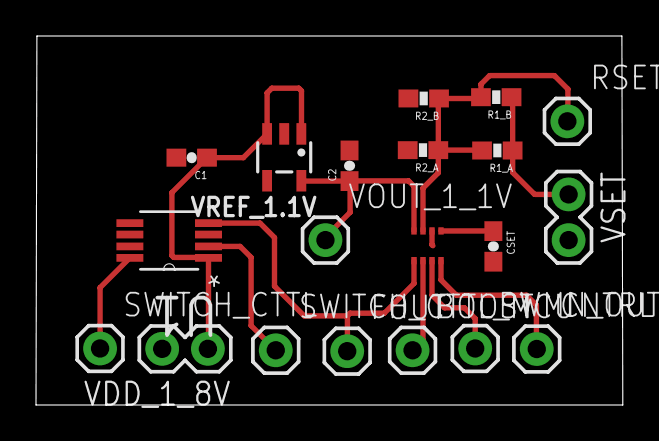
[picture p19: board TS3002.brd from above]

Board: 2 copper layers, 32.6 x 20.5 mm, 21 parts (0 on the bottom side), 12 nets.

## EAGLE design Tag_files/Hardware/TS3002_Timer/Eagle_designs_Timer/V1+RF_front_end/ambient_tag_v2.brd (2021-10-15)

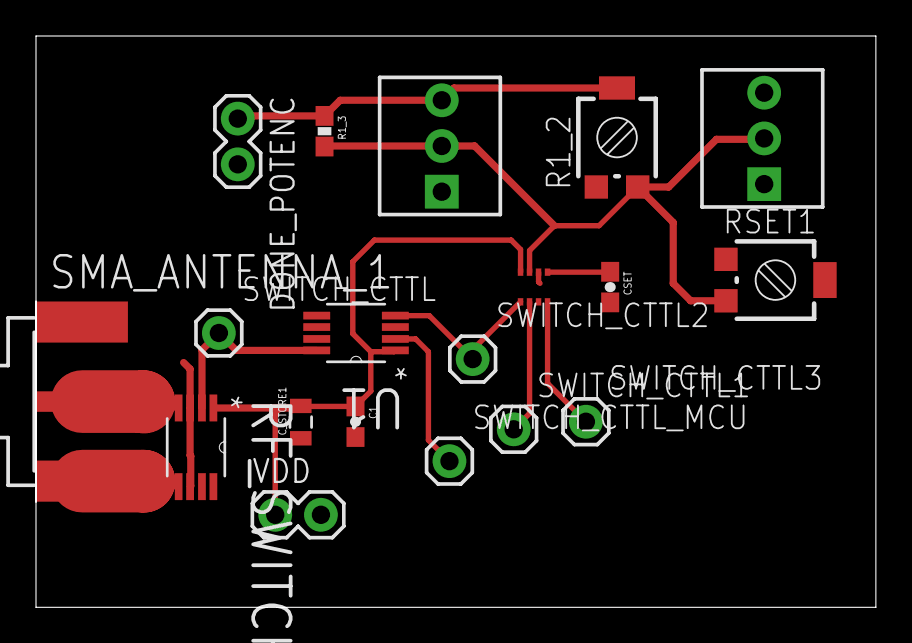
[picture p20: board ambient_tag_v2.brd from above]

Board: 2 copper layers, 46.7 x 31.7 mm, 20 parts (0 on the bottom side), 12 nets.

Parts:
C1: 0.1 uF; 0603-CAP
CSET: 8.5 pF; 0603-CAP
C_STORE1: 4.7uF; 0805
DONE_POTENC: 1X02
LOGO1: OSHW-LOGOL; OSHW-LOGO-L
R1, R2: TRIMPOT; 3362U-2
R1_2: RTRIM3314G
R1_3: 0603-RES
RF_SWITCH: ADG919BRMZ; SOP65P490X110-8N
RSET1: RTRIM3314G
SMA_ANTENNA_1: SMA-142-0701-881/886; J502-ND-142-0701-881/886
SWITCH_CTTL, SWITCH_CTTL1, SWITCH_CTTL2, SWITCH_CTTL3: M01PTH; 1X01
SWITCH_CTTL_MCU: M01PTH; 1X01
U1: ADG902BRMZ; SOP65P490X110-8N
U$1: TDFN22-8
VDD: 1X02

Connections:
CTRL: SWITCH_CTTL3.1, U$1.4
GND: C1.2, CSET.2, C_STORE1.1, DONE_POTENC.2, R1.1, RF_SWITCH.3, RF_SWITCH.6, RF_SWITCH.7, RSET1.2, U1.3, U1.5, U1.6, U1.7, U$1.6, VDD.2
unnamed: DONE_POTENC.1, R1_2.2, R1_3.1, R2.3
unnamed: SWITCH_CTTL_MCU.1, U1.2
unnamed: SWITCH_CTTL1.1, U$1.2
unnamed: R1.2, R1_2.1, R1_3.2, R2.2, RSET1.1, U$1.7
unnamed: CSET.1, U$1.5
RF2: RF_SWITCH.5, SMA_ANTENNA_1.G@1, SMA_ANTENNA_1.G@2, SMA_ANTENNA_1.G@3, SMA_ANTENNA_1.G@4
RFC: RF_SWITCH.4, SMA_ANTENNA_1.1
SWITCH_CTTL: RF_SWITCH.2, SWITCH_CTTL.1, U1.8
TIMER: SWITCH_CTTL2.1, U1.4, U$1.1
VDD_1.8V: C1.1, C_STORE1.2, RF_SWITCH.1, U1.1, U$1.8, VDD.1

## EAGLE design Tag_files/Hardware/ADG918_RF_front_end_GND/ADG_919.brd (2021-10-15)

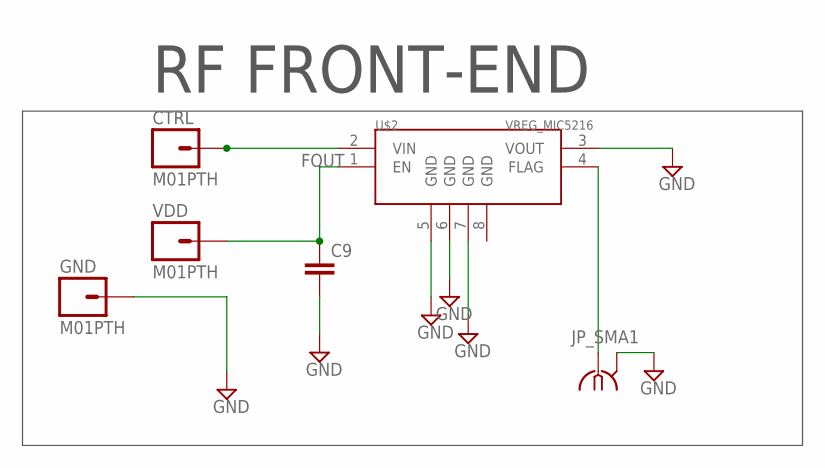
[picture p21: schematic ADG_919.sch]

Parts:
C9: CAP0603-CAP; 0603-CAP
CTRL: M01PTH; 1X01
GND: M01PTH; 1X01
JP_SMA1: SMA-142-0701-881/886; J502-ND-142-0701-881/886
U$2: VREG_MIC5216; MSOP8
VDD: M01PTH; 1X01

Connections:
FOUT: CTRL.1, U$2.2 (VIN)
GND: C9.2, GND.1, JP_SMA1.G@1 (2), JP_SMA1.G@2 (2), JP_SMA1.G@3 (2), JP_SMA1.G@4 (2), U$2.3 (VOUT), U$2.5 (GND), U$2.6 (GND), U$2.7 (GND)
unnamed: C9.1, U$2.1 (EN), VDD.1
unnamed: JP_SMA1.1, U$2.4 (FLAG)

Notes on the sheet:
RF FRONT-END

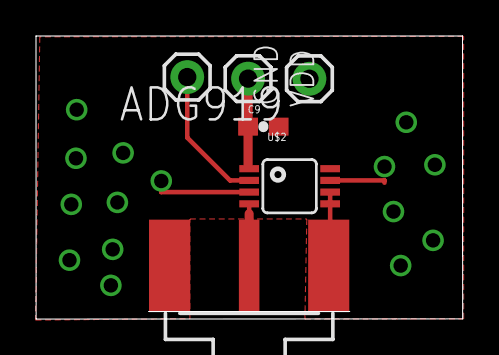
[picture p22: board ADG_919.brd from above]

Board: 2 copper layers, 23.7 x 15.7 mm, 6 parts (0 on the bottom side), 4 nets.

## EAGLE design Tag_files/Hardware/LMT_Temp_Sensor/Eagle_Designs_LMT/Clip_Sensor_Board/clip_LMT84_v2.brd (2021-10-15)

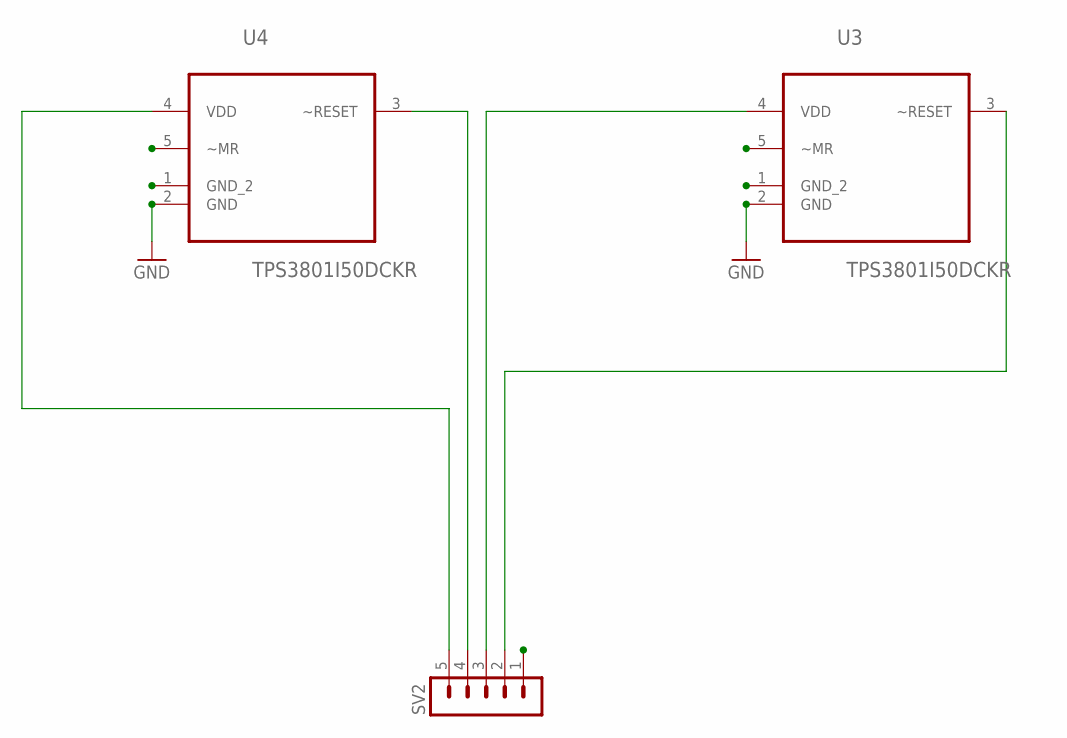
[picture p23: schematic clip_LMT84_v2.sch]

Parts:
SV2: MA05-1
U3, U4: TPS3801I50DCKR; SOT65P210X110-5N

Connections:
GND: SV2.1, U3.1 (GND_2), U3.2 (GND), U3.5 (~MR), U4.1 (GND_2), U4.2 (GND), U4.5 (~MR)
unnamed: SV2.3, U3.4 (VDD)
unnamed: SV2.5, U4.4 (VDD)
unnamed: SV2.4, U4.3 (~RESET)
VOUT_AIR: SV2.2, U3.3 (~RESET)

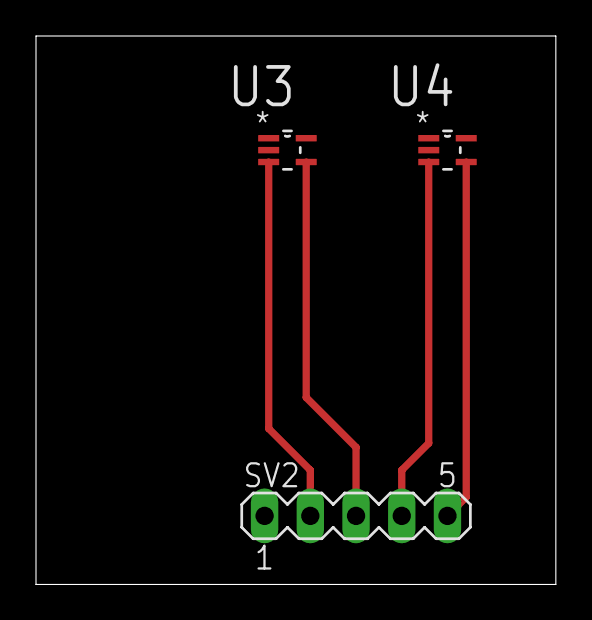
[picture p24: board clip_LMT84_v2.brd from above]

Board: 2 copper layers, 28.9 x 30.5 mm, 3 parts (0 on the bottom side), 5 nets.

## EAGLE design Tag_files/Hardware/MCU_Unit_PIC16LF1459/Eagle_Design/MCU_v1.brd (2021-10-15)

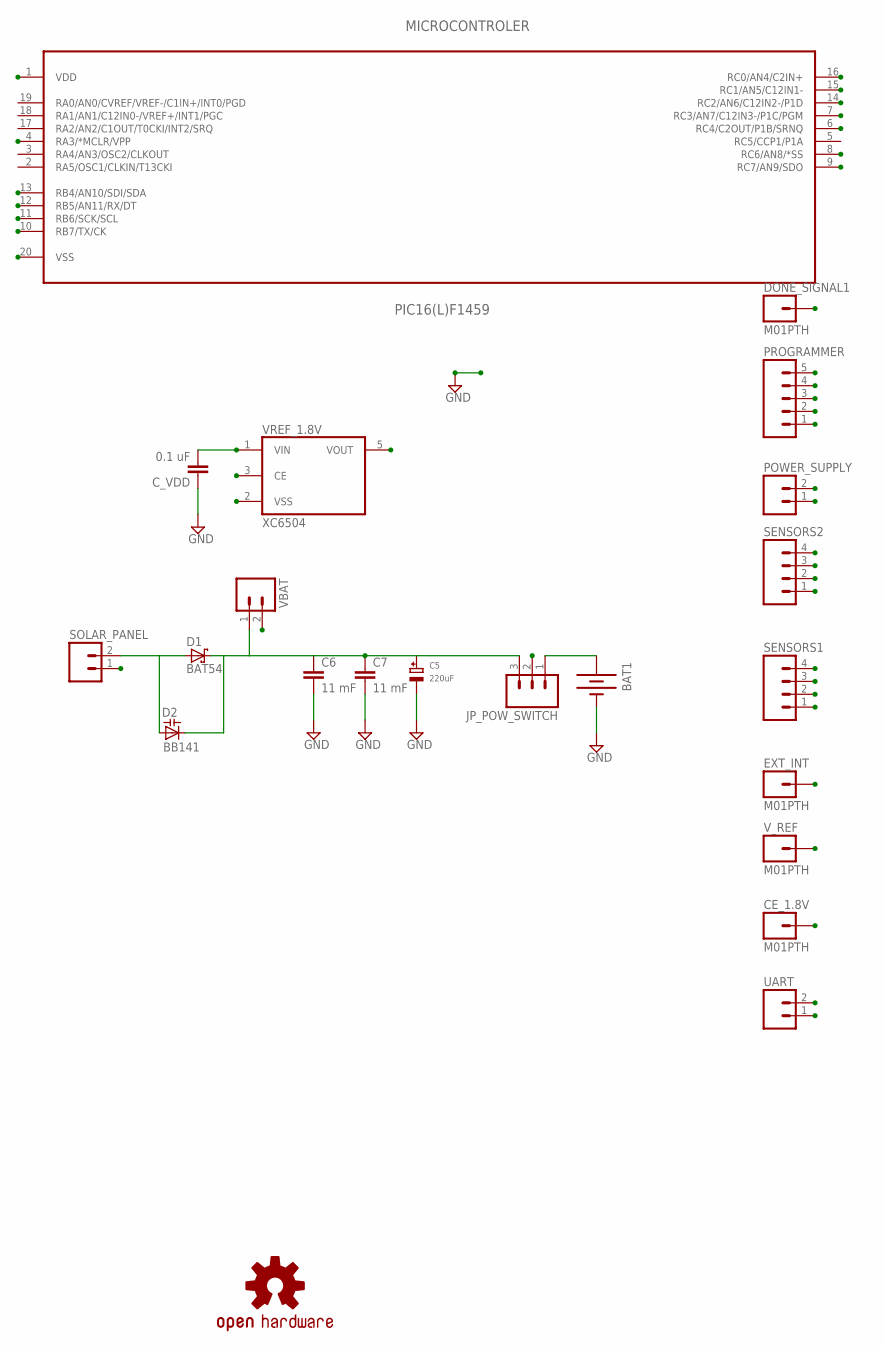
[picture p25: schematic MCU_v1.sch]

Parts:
BAT1: BATTERY20PTH_LAB; BATTCOM_20MM_PTH
C5: 220uF; EIA7343-31/D-R
C6, C7: 11 mF; 1210
CE_1.8V: M01PTH; 1X01
C_VDD: 0.1 uF; 0603-CAP
D1: BAT54; SOT23
D2: BB141; SOD523
DONE_SIGNAL1: M01PTH; 1X01
EXT_INT: M01PTH; 1X01
JP_POW_SWITCH: M03LOCK; 1X03_LOCK
LOGO1: OSHW-LOGOL; OSHW-LOGO-L
MICROCONTROLER: PIC16(L)F1459; SOP65P780X200-20N
POWER_SUPPLY: M02PTH; 1X02
PROGRAMMER: M05PTH; 1X05
SENSORS1, SENSORS2: M04LOCK; 1X04_LOCK
SOLAR_PANEL: M02PTH; 1X02
UART: M02PTH; 1X02
VBAT: M02PTH; 1X02
VREF_1.8V: XC6504; SOT23-5
V_REF: M01PTH; 1X01

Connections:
CE: CE_1.8V.1, VREF_1.8V.3 (CE)
DAC1: MICROCONTROLER.14 (RC2/AN6/C12IN2-/P1D), SENSORS2.4
DEL: C5.+, C6.1, C7.1, D1.3 (C), D2.C, JP_POW_SWITCH.3, VBAT.1
DONE_OUT: DONE_SIGNAL1.1, MICROCONTROLER.7 (RC3/AN7/C12IN3-/P1C/PGM)
GND: BAT1.2 (-), C5.-, C6.2, C7.2, C_VDD.1, MICROCONTROLER.20 (VSS), POWER_SUPPLY.1, PROGRAMMER.3, SENSORS1.1, SENSORS1.3, SOLAR_PANEL.1, UART.2, VBAT.2, VREF_1.8V.2 (VSS)
MCLR: MICROCONTROLER.4 (RA3/*MCLR/VPP), PROGRAMMER.5
unnamed: BAT1.1 (+), JP_POW_SWITCH.1
RB4: MICROCONTROLER.13 (RB4/AN10/SDI/SDA), SENSORS2.3
RB5: MICROCONTROLER.12 (RB5/AN11/RX/DT), SENSORS2.2
RB6: MICROCONTROLER.11 (RB6/SCK/SCL), SENSORS2.1
SENSOR1: MICROCONTROLER.8 (RC6/AN8/*SS), SENSORS1.4
SENSOR2: MICROCONTROLER.9 (RC7/AN9/SDO), SENSORS1.2
SOLAR_CELL: D1.1 (A), D2.A, SOLAR_PANEL.2
SPCLK: EXT_INT.1, MICROCONTROLER.15 (RC1/AN5/C12IN1-), PROGRAMMER.1
SPDAT: MICROCONTROLER.16 (RC0/AN4/C2IN+), PROGRAMMER.2, V_REF.1
SWITCH_CTTL: MICROCONTROLER.6 (RC4/C2OUT/P1B/SRNQ)
UART_TX: MICROCONTROLER.10 (RB7/TX/CK), UART.1
VDD: C_VDD.2, JP_POW_SWITCH.2, VREF_1.8V.1 (VIN)
VDD_1.8V: MICROCONTROLER.1 (VDD), POWER_SUPPLY.2, PROGRAMMER.4, VREF_1.8V.5 (VOUT)

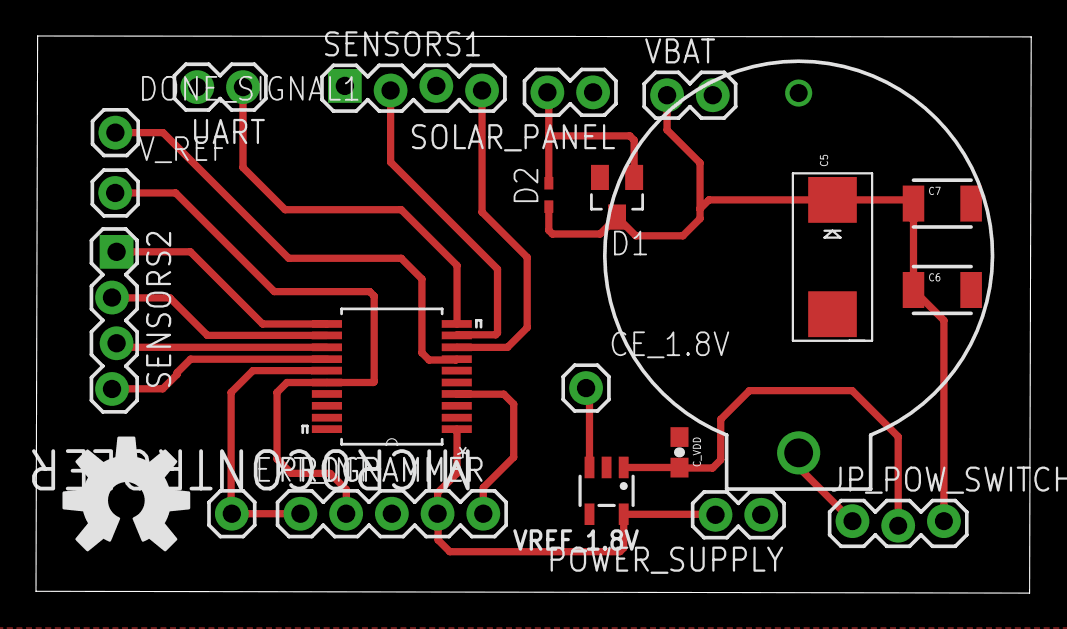
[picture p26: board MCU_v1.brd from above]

Board: 2 copper layers, 55.3 x 31.0 mm, 22 parts (0 on the bottom side), 18 nets.

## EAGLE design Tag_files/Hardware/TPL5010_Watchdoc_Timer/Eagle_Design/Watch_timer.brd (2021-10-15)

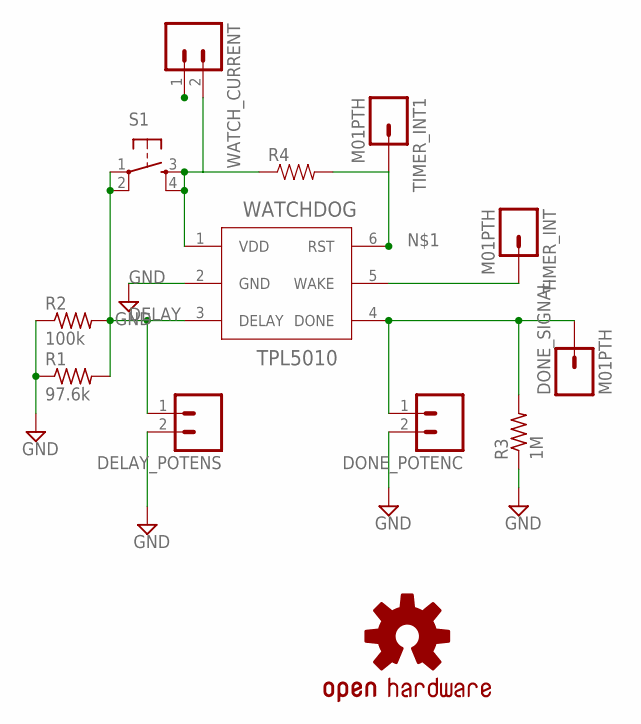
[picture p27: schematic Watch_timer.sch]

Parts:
DELAY_POTENS: M02PTH; 1X02
DONE_POTENC: M02PTH; 1X02
DONE_SIGNAL: M01PTH; 1X01
LOGO1: OSHW-LOGOL; OSHW-LOGO-L
R1: 97.6k; R0805
R2: 100k; R0805
R3: 1M; R0805
R4: RESISTOR0603-RES; 0603-RES
S1: TAC_SWITCHSMD; TACTILE_SWITCH_SMD
TIMER_INT, TIMER_INT1: M01PTH; 1X01
WATCHDOG: TPL5010; TSOT-23
WATCH_CURRENT: M02PTH; 1X02

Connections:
DELAY: DELAY_POTENS.1, R1.2, R2.2, S1.1, S1.2, WATCHDOG.3 (DELAY)
DONE: DONE_POTENC.1, DONE_SIGNAL.1, R3.2, WATCHDOG.4 (DONE)
GND: DELAY_POTENS.2, DONE_POTENC.2, R1.1, R2.1, R3.1, WATCHDOG.2 (GND)
unnamed: R4.2, TIMER_INT1.1, WATCHDOG.6 (RST)
unnamed: TIMER_INT.1, WATCHDOG.5 (WAKE)
VDD: WATCH_CURRENT.1
VDD_WATCH: R4.1, S1.3, S1.4, WATCHDOG.1 (VDD), WATCH_CURRENT.2

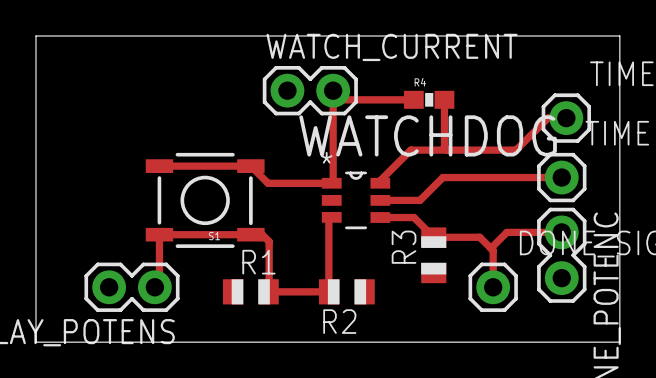
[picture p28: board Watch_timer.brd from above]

Board: 2 copper layers, 32.4 x 17.0 mm, 13 parts (0 on the bottom side), 6 nets.

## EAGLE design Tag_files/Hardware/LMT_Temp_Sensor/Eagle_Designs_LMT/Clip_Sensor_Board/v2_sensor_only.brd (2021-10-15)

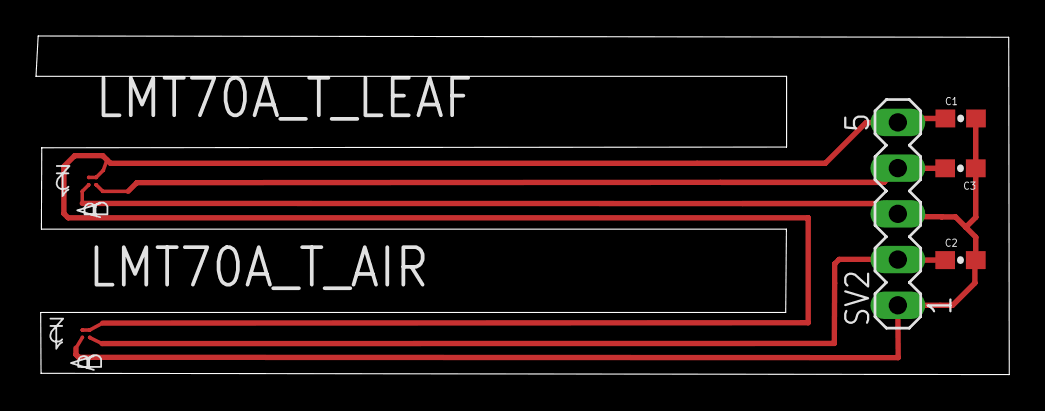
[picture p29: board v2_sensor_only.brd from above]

Board: 2 copper layers, 54.1 x 18.8 mm, 6 parts (0 on the bottom side), 4 nets.

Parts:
C1: 0.1uF; 0603-CAP
C2, C3: 100 pF; 0603-CAP
LMT70A_T_AIR, LMT70A_T_LEAF: INA216A1YFFR; BGA4C40P2X2_76X76X63
SV2: MA05-1

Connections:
GND_A: C1.2, C2.2, C3.1, LMT70A_T_AIR.A1, LMT70A_T_LEAF.A1, SV2.1, SV2.3
VDD_A: C1.1, LMT70A_T_AIR.A2, LMT70A_T_AIR.B2, LMT70A_T_LEAF.A2, LMT70A_T_LEAF.B2, SV2.5
VOUT_AIR: C2.1, LMT70A_T_AIR.B1, SV2.2
VOUT_LEAF: C3.2, LMT70A_T_LEAF.B1, SV2.4

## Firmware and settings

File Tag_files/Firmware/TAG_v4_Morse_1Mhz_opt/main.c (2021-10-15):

/*
Spiros Daskalakis 
Last Version: 31/1/2018
Email: daskalakispiros@gmail.com
Website: www.daskalakispiros.com
*/

#include <stdio.h>
#include <string.h>
#include "mcc_generated_files/mcc.h"
#include "BackscatterComm.h"
#include "main.h"
#include "pic16lf1459.h"
#include <math.h>

/*
                         Main application
 *///
    char  packet1[PACKETLENGTH]=0;
    char  packet2[PACKETLENGTHHAMMING]=0;
    char  nocodedbit[ID_LENGTH+UTILITY_LENGTH+INFOWORD_LENGTH]=0;
     
    char   *preamble="1010101111";
    char   *Fixeddata="0111100011";
    char   *packet="1010101111010100111100011" ;
    char   *message = "2.";
    
    char str8[6]=0;
    
    double temp=0;
    int hundreds=0;
    int tens=0; 
    int units=0;
    int tenths=0;
    int hundredths=0;
    int thousandths=0; 
    int tenthousandths=0;
    
	 double remainder=0;
     
     
    double IN_STRAY_CAP_TO_GND=26.70;
    double IN_EXTRA_CAP_TO_GND=0.0;
    double IN_CAP_TO_GND=0.0;
    double capacitance=0.0;
    
    double FactorA= -1.064200E-09;
	double FactorB= -5.759725E-06;
	double FactorC= -1.789883E-01;
	double FactorD=  2.048570E+02;
    double TemporC1=0;
    double TemporC2=0;
    double TempDIFF=0;
    
    double ADC0mVolt=0;
    double ADC1mVolt=0;
        
    double ADC0mVolt1=0;
    double ADC0mVolt2=0;

    double voltref=2042;
    int ADCres=1023;
    int delay=2000;
    double sensor0=0;
    double sensor1=0;
    
    int NODE_ID=1;
    int SENSORID=0;
    
    int sleep=0;
    
    
    // Morse character codes: last 5  bits dits/dahs, fist 3 bits - length


void main(void)
{
    int i=0;
  
    // initialize the device
    SYSTEM_Initialize();
    uint8_t count=0;
    
//FVR_Initialize();
  
    // When using interrupts, you need to set the Global and Peripheral Interrupt Enable bits
    // Use the following macros to:
    if (sleep==1)
    {    
       // Enable the Global Interrupts
       INTERRUPT_GlobalInterruptEnable();
    }
    else
    {
      // Disable the Global Interrupts
    INTERRUPT_GlobalInterruptDisable();
    }   
    
    INTERRUPT_GlobalInterruptEnable();
        
    // Enable the Peripheral Interrupts
    INTERRUPT_PeripheralInterruptEnable();

    // Disable the Peripheral Interrupts
    //INTERRUPT_PeripheralInterruptDisable();
   ADC_Initialize();
     
   printf("Start\n");
    while (1)
    {
        // Take data from sensors 
        
          *packet1=0;

         LATC3=1;
         //leaf temp
         sensor0= ADC_GetConversion(channel_AN8);
         ADC0mVolt1 =(voltref/ADCres)*sensor0; 
       
         
         //air temp
         sensor1= ADC_GetConversion(channel_AN9);
         ADC0mVolt2 =(voltref/ADCres)*sensor1; 
            
         
         //Close adc  
         ADCON0 = 0x00; 
         LATC3=0;
         
        
          ADC0mVolt2 =995.050;
          ADC0mVolt1 =992.227;

         TemporC1 = (double)FactorA*pow(ADC0mVolt1,3)+ (double)FactorB*pow(ADC0mVolt1,2)+ (double)FactorC*(ADC0mVolt1) + FactorD;
         TemporC2 = (double)FactorA*pow(ADC0mVolt2,3)+ (double)FactorB*pow(ADC0mVolt2,2)+ (double)FactorC*(ADC0mVolt2) + FactorD;
         TempDIFF=(TemporC2-TemporC1+6)*100;
         
         //printf("%f\n", TempDIFF);
         
           TempDIFF *= 10000;//250625.
	       temp = (double)TempDIFF;//250625

	       tens = temp/100000;//2
	       remainder = temp - tens*100000;//50625
	       units = remainder/10000;//5
           
	      // remainder = remainder - units*10000;//625
	      // tenths = remainder/1000;//0
	      // remainder = remainder - tenths*1000;//625
	      // hundredths = remainder/100;//6
   
       //sprintf(str8, "%d%d%d%d", tens, units, tenths, hundredths);
         
        sprintf(str8,"%d%d", tens,units );
       
        printf("%s\n",str8);

        SENSORID=0;  
        sensor0=483;

       char *c = str8;
       for( ; *c ; c++ ) 
       {
            sendChar( *c );
            printf("%c \n", *c );
       }
	

         if (sleep==1)
          {     
           SLEEP(); // go to sleep ->interupt at pin 15 
           }
           else
          {
            int waitind; 
             for(waitind = 0; waitind<400; waitind++){  
               _nop();
               _nop();
            }              
          }
           
    }
    
}


  
          // Add your application code
             //LATC4=~LATC4; 
             //DACCON1  = 31 ;//mexri 31 paei 
            //_nop();
            //DACCON1  = 30;


void dit_dah(int index)
{
	
    int i;
    LATC4=1;
	if (index==1)
	{
		for(i = 0; i < delay; ++i)
		{
		      _nop();
              LATC4=~LATC4;
		 }
	}
	if(index==3)
	{
		for(i = 0; i < delay; ++i)
		{
		      _nop();
              LATC4=~LATC4;
		}
		for(i = 0; i < delay; ++i)
		{
			  _nop();	  
              LATC4=~LATC4;
		}
		for(i = 0; i < delay; ++i)
		{
			  _nop();
              LATC4=~LATC4;
		}
	}
     LATC4=0;
	 for(i = 0; i < delay; ++i)
	 {
	          _nop();
	 }
}


void sendChar(unsigned char a)
{
 int i;
 if (a=='0'){
 dit_dah(3); dit_dah(3); dit_dah(3); dit_dah(3);  dit_dah(3);}
 else if  (a=='1'){
 dit_dah(1);dit_dah(3); dit_dah(3); dit_dah(3);  dit_dah(3);}
 else if  (a=='2'){
 dit_dah(1);dit_dah(1); dit_dah(3); dit_dah(3);  dit_dah(3);}
  else if  (a=='3'){
 dit_dah(1);dit_dah(1); dit_dah(1);  dit_dah(3);  dit_dah(3);}
 else if  (a=='4'){
 dit_dah(1);dit_dah(1); dit_dah(1);  dit_dah(1); dit_dah(3);}
 else if  (a=='5'){
 dit_dah(1);dit_dah(1); dit_dah(1);dit_dah(1);  dit_dah(1);}
 else if  (a=='6'){
 dit_dah(3);dit_dah(1); dit_dah(1);dit_dah(1);  dit_dah(1);}
 else if  (a=='7'){
 dit_dah(3);dit_dah(3); dit_dah(1);dit_dah(1);  dit_dah(1);}
  else if  (a=='8'){
 dit_dah(3);dit_dah(3); dit_dah(3);dit_dah(1);  dit_dah(1);}
 else if  (a=='9'){
 dit_dah(3);dit_dah(3); dit_dah(3);dit_dah(3);  dit_dah(1);}
 else if  (a=='-'){
 dit_dah(3); dit_dah(1); dit_dah(1); dit_dah(1); dit_dah(1); dit_dah(3);
 }
 else if  (a=='.'){
 dit_dah(1);dit_dah(3); dit_dah(1); dit_dah(3); dit_dah(1); dit_dah(3);
 }

 //pause(2); // 3 dots between characters, 1 was already after the beep
 for(i = 0; i < delay; ++i){
         	  _nop();		     
         	}// gia na ftiaxo tous idios xronous
 for(i = 0; i < delay; ++i){
         	  _nop();

         	}// gia na ftiaxo tous idios xronous
 
}

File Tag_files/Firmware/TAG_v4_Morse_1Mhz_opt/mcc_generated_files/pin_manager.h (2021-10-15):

/**
  @Generated Pin Manager Header File

  @Company:
    Microchip Technology Inc.

  @File Name:
    pin_manager.h

  @Summary:
    This is the Pin Manager file generated using MPLAB(c) Code Configurator

  @Description:
    This header file provides implementations for pin APIs for all pins selected in the GUI.
    Generation Information :
        Product Revision  :  MPLAB(c) Code Configurator - 4.26
        Device            :  PIC16LF1459
        Version           :  1.01
    The generated drivers are tested against the following:
        Compiler          :  XC8 1.35
        MPLAB             :  MPLAB X 3.40

    Copyright (c) 2013 - 2015 released Microchip Technology Inc.  All rights reserved.

    Microchip licenses to you the right to use, modify, copy and distribute
    Software only when embedded on a Microchip microcontroller or digital signal
    controller that is integrated into your product or third party product
    (pursuant to the sublicense terms in the accompanying license agreement).

    You should refer to the license agreement accompanying this Software for
    additional information regarding your rights and obligations.

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
*/


#ifndef PIN_MANAGER_H
#define PIN_MANAGER_H

#define INPUT   1
#define OUTPUT  0

#define HIGH    1
#define LOW     0

#define ANALOG      1
#define DIGITAL     0

#define PULL_UP_ENABLED      1
#define PULL_UP_DISABLED     0

// get/set RB5 procedures
#define RB5_SetHigh()    do { LATBbits.LATB5 = 1; } while(0)
#define RB5_SetLow()   do { LATBbits.LATB5 = 0; } while(0)
#define RB5_Toggle()   do { LATBbits.LATB5 = ~LATBbits.LATB5; } while(0)
#define RB5_GetValue()         PORTBbits.RB5
#define RB5_SetDigitalInput()   do { TRISBbits.TRISB5 = 1; } while(0)
#define RB5_SetDigitalOutput()  do { TRISBbits.TRISB5 = 0; } while(0)
#define RB5_SetPullup()     do { WPUBbits.WPUB5 = 1; } while(0)
#define RB5_ResetPullup()   do { WPUBbits.WPUB5 = 0; } while(0)
#define RB5_SetAnalogMode() do { ANSELBbits.ANSB5 = 1; } while(0)
#define RB5_SetDigitalMode()do { ANSELBbits.ANSB5 = 0; } while(0)

// get/set RB7 procedures
#define RB7_SetHigh()    do { LATBbits.LATB7 = 1; } while(0)
#define RB7_SetLow()   do { LATBbits.LATB7 = 0; } while(0)
#define RB7_Toggle()   do { LATBbits.LATB7 = ~LATBbits.LATB7; } while(0)
#define RB7_GetValue()         PORTBbits.RB7
#define RB7_SetDigitalInput()   do { TRISBbits.TRISB7 = 1; } while(0)
#define RB7_SetDigitalOutput()  do { TRISBbits.TRISB7 = 0; } while(0)
#define RB7_SetPullup()     do { WPUBbits.WPUB7 = 1; } while(0)
#define RB7_ResetPullup()   do { WPUBbits.WPUB7 = 0; } while(0)

// get/set RC1 procedures
#define RC1_SetHigh()    do { LATCbits.LATC1 = 1; } while(0)
#define RC1_SetLow()   do { LATCbits.LATC1 = 0; } while(0)
#define RC1_Toggle()   do { LATCbits.LATC1 = ~LATCbits.LATC1; } while(0)
#define RC1_GetValue()         PORTCbits.RC1
#define RC1_SetDigitalInput()   do { TRISCbits.TRISC1 = 1; } while(0)
#define RC1_SetDigitalOutput()  do { TRISCbits.TRISC1 = 0; } while(0)
#define RC1_SetAnalogMode() do { ANSELCbits.ANSC1 = 1; } while(0)
#define RC1_SetDigitalMode()do { ANSELCbits.ANSC1 = 0; } while(0)

// get/set IO_RC3 aliases
#define IO_RC3_TRIS               TRISCbits.TRISC3
#define IO_RC3_LAT                LATCbits.LATC3
#define IO_RC3_PORT               PORTCbits.RC3
#define IO_RC3_ANS                ANSELCbits.ANSC3
#define IO_RC3_SetHigh()            do { LATCbits.LATC3 = 1; } while(0)
#define IO_RC3_SetLow()             do { LATCbits.LATC3 = 0; } while(0)
#define IO_RC3_Toggle()             do { LATCbits.LATC3 = ~LATCbits.LATC3; } while(0)
#define IO_RC3_GetValue()           PORTCbits.RC3
#define IO_RC3_SetDigitalInput()    do { TRISCbits.TRISC3 = 1; } while(0)
#define IO_RC3_SetDigitalOutput()   do { TRISCbits.TRISC3 = 0; } while(0)
#define IO_RC3_SetAnalogMode()  do { ANSELCbits.ANSC3 = 1; } while(0)
#define IO_RC3_SetDigitalMode() do { ANSELCbits.ANSC3 = 0; } while(0)

// get/set IO_RC4 aliases
#define IO_RC4_TRIS               TRISCbits.TRISC4
#define IO_RC4_LAT                LATCbits.LATC4
#define IO_RC4_PORT               PORTCbits.RC4
#define IO_RC4_SetHigh()            do { LATCbits.LATC4 = 1; } while(0)
#define IO_RC4_SetLow()             do { LATCbits.LATC4 = 0; } while(0)
#define IO_RC4_Toggle()             do { LATCbits.LATC4 = ~LATCbits.LATC4; } while(0)
#define IO_RC4_GetValue()           PORTCbits.RC4
#define IO_RC4_SetDigitalInput()    do { TRISCbits.TRISC4 = 1; } while(0)
#define IO_RC4_SetDigitalOutput()   do { TRISCbits.TRISC4 = 0; } while(0)

// get/set channel_AN8 aliases
#define channel_AN8_TRIS               TRISCbits.TRISC6
#define channel_AN8_LAT                LATCbits.LATC6
#define channel_AN8_PORT               PORTCbits.RC6
#define channel_AN8_ANS                ANSELCbits.ANSC6
#define channel_AN8_SetHigh()            do { LATCbits.LATC6 = 1; } while(0)
#define channel_AN8_SetLow()             do { LATCbits.LATC6 = 0; } while(0)
#define channel_AN8_Toggle()             do { LATCbits.LATC6 = ~LATCbits.LATC6; } while(0)
#define channel_AN8_GetValue()           PORTCbits.RC6
#define channel_AN8_SetDigitalInput()    do { TRISCbits.TRISC6 = 1; } while(0)
#define channel_AN8_SetDigitalOutput()   do { TRISCbits.TRISC6 = 0; } while(0)
#define channel_AN8_SetAnalogMode()  do { ANSELCbits.ANSC6 = 1; } while(0)
#define channel_AN8_SetDigitalMode() do { ANSELCbits.ANSC6 = 0; } while(0)

// get/set channel_AN9 aliases
#define channel_AN9_TRIS               TRISCbits.TRISC7
#define channel_AN9_LAT                LATCbits.LATC7
#define channel_AN9_PORT               PORTCbits.RC7
#define channel_AN9_ANS                ANSELCbits.ANSC7
#define channel_AN9_SetHigh()            do { LATCbits.LATC7 = 1; } while(0)
#define channel_AN9_SetLow()             do { LATCbits.LATC7 = 0; } while(0)
#define channel_AN9_Toggle()             do { LATCbits.LATC7 = ~LATCbits.LATC7; } while(0)
#define channel_AN9_GetValue()           PORTCbits.RC7
#define channel_AN9_SetDigitalInput()    do { TRISCbits.TRISC7 = 1; } while(0)
#define channel_AN9_SetDigitalOutput()   do { TRISCbits.TRISC7 = 0; } while(0)
#define channel_AN9_SetAnalogMode()  do { ANSELCbits.ANSC7 = 1; } while(0)
#define channel_AN9_SetDigitalMode() do { ANSELCbits.ANSC7 = 0; } while(0)

/**
   @Param
    none
   @Returns
    none
   @Description
    GPIO and peripheral I/O initialization
   @Example
    PIN_MANAGER_Initialize();
 */
void PIN_MANAGER_Initialize (void);

/**
 * @Param
    none
 * @Returns
    none
 * @Description
    Interrupt on Change Handling routine
 * @Example
    PIN_MANAGER_IOC();
 */
void PIN_MANAGER_IOC(void);



#endif // PIN_MANAGER_H
/**
 End of File
*/

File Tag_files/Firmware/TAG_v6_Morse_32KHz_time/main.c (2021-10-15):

/*
Spiros Daskalakis 
Last Version: 31/1/2018
Email: daskalakispiros@gmail.com
Website: www.daskalakispiros.com
*/

#include <stdio.h>
#include <string.h>
#include "mcc_generated_files/mcc.h"
#include "BackscatterComm.h"
#include "main.h"
#include "pic16lf1459.h"
#include <math.h>


    
    char str8[10]=0;
    int delay=4;  
      int v;
    int NODE_ID=1;
    int SENSORID=0;
    int sleep=0;
    int sensor0=0;
    int sensor1=0;
void main(void)
{
 
  
    // initialize the device
    SYSTEM_Initialize();
    uint8_t count=0;
    
//FVR_Initialize();
  
    // When using interrupts, you need to set the Global and Peripheral Interrupt Enable bits
    // Use the following macros to:
    if (sleep==1)
    {    
       // Enable the Global Interrupts
       INTERRUPT_GlobalInterruptEnable();
    }
    else
    {
      // Disable the Global Interrupts
    INTERRUPT_GlobalInterruptDisable();
    }   
    
    //INTERRUPT_GlobalInterruptEnable();
        
    // Enable the Peripheral Interrupts
    //INTERRUPT_PeripheralInterruptEnable();

    // Disable the Peripheral Interrupts
    //INTERRUPT_PeripheralInterruptDisable();
   ADC_Initialize();
   DAC_Initialize();
     
   printf("Start\n");
    while (1)
    {
         
         DACEN=0;
         //LATC3=1;
         //leaf temp
         
         sensor0= ADC_GetConversion(channel_AN8); 
        
         
         //air temp
         sensor1= ADC_GetConversion(channel_AN9);
         
         //Close adc  
         ADCON0 = 0x00; 
         
         //sprintf(str8,"%dE%d", sensor0,sensor1);
        //sprintf(str8,"%dE%d", ADC_GetConversion(channel_AN8), ADC_GetConversion(channel_AN9));
         
         
         
         //LATC3=0;
       
        DACEN=0;  
        DACCON1  = 0 ; //mexri 31 paei  
        LATB4 = 1;
         
       sprintf(str8,"%dE%d", 2, 4);

       char *c = str8;
       for( ; *c ; c++ ) 
       {
            sendChar( *c );
       }
	
       DACEN=0;  // Close DAC 
       LATB4 = 0; // Close timer 
         if (sleep==1) { 
             
             
             SLEEP(); // go to sleep ->interupt at pin 15 
           }
       
       for(v = 0; v < 250; ++v)
	    {
		      _nop();
	   }
       
    
    }
    
}

void dot()
{
    int i;
    LATC3=1;
	
	for(i = 0; i < delay; ++i)
	{
		      _nop();
	}
     LATC3=0;
	 for(i = 0; i < delay; ++i)
	 {
	          _nop();
	 }
}

void dash()
{
    int i;
    LATC3=1;
	
	
		for(i = 0; i < delay; ++i)
		{
		      _nop();
		}
    for(i = 0; i < delay; ++i)
		{
		      _nop();
		}
		
    for(i = 0; i < delay; ++i)
		{
		      _nop();
		}

     LATC3=0;
	 for(i = 0; i < delay; ++i)
	 {
	          _nop();
	 }
}



void sendChar(unsigned char a)
{
 int i;
 if (a=='0'){
  dash();dash();dash();dash();dash();}
 else if  (a=='1'){
  dot(); dash(); dash(); dash(); dash();}
 else if  (a=='2'){
  dot();  dot(); dash(); dash(); dash();}
  else if  (a=='3'){
    dot();  dot(); dot(); dash(); dash();}
 else if  (a=='4'){
  dot(); dot(); dot(); dot(); dash();}
 else if  (a=='5'){
  dot();  dot(); dot(); dot(); dot();}
 else if  (a=='6'){
  dash(); dot(); dot(); dot(); dot();}
 else if  (a=='7'){
   dash(); dash();  dot(); dot(); dot();}
  else if  (a=='8'){
    dash();dash();dash();  dot(); dot(); }
 else if  (a=='9'){
     dash();dash();dash();dash(); dot();}
 else if  (a=='E'){
      dot();}
 
 //pause(2); // 3 dots between characters, 1 was already after the beep
 for(i = 0; i < delay; ++i){
         	  _nop();		     
         	}// gia na ftiaxo tous idios xronous
 for(i = 0; i < delay; ++i){
         	  _nop();

         	}// gia na ftiaxo tous idios xronous 
}

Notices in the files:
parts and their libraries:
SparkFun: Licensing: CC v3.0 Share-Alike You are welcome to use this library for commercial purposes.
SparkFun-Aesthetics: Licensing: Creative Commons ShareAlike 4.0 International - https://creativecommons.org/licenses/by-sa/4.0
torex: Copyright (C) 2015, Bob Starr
